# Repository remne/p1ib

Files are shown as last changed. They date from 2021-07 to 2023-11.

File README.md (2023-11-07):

- [P1IB - P1 Interface Bridge](#p1ib---p1-interface-bridge)
  - [Features](#features)
  - [Hardware](#hardware)
  - [Supported smart power meters](#supported-smart-power-meters)
- [Powermeter prerequisite](#powermeter-prerequisite)
- [First time usage](#first-time-usage)
- [Menues](#menues)
  - [Dashboard](#dashboard)
  - [Settings](#settings)
  - [Advanced Settings](#advanced-settings)
  - [Reduced Data Mode](#reduced-data-mode)
- [Firmware update](#firmware-update)
- [Home Assistant](#home-assistant)
  - [Configure MQTT in P1IB](#configure-mqtt-in-p1ib)
  - [Setup the Energy board with p1ib sensors](#setup-the-energy-board-with-p1ib-sensors)
  - [Examples of cards in Home Assistant](#examples-of-cards-in-home-assistant)
    - [Apex charts with energy consumption and electricity spot price from nordpool](#apex-charts-with-energy-consumption-and-electricity-spot-price-from-nordpool)
    - [Example: Current gauges](#example-current-gauges)
  - [Examples of automations in Home Assistant](#examples-of-automations-in-home-assistant)
    - [Example: Disable power switch when fuse amperage is above a given threshold](#example-disable-power-switch-when-fuse-amperage-is-above-a-given-threshold)
- [Homey App](#homey-app)
- [FAQ / Trouble shooting](#faq--trouble-shooting)

# P1IB - P1 Interface Bridge
P1IB (pronounced p-l-i-b) is a software (and hardware) designed to read and parse advanced power meter (AMS) telegrams from the P1
interface port (RJ12) and to send the result to a consumer service, for instance Home Assistant.

Visit [https://remne.tech](https://remne.tech) for more information.

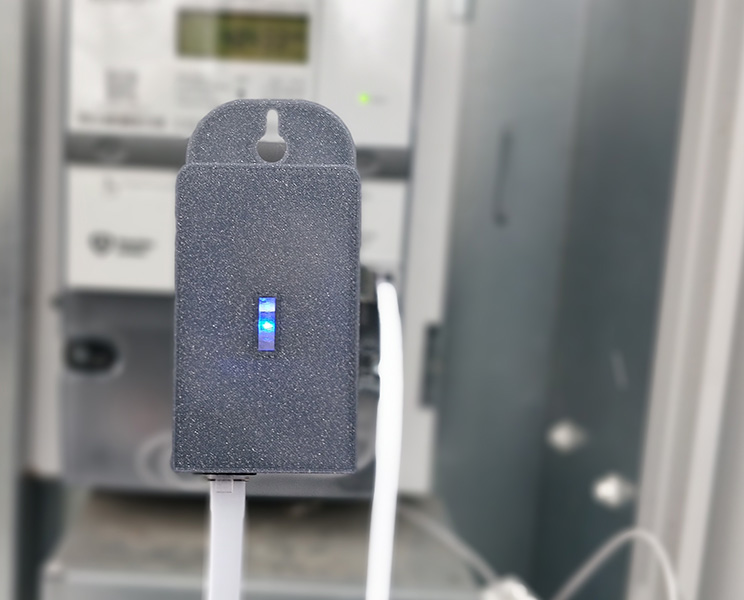
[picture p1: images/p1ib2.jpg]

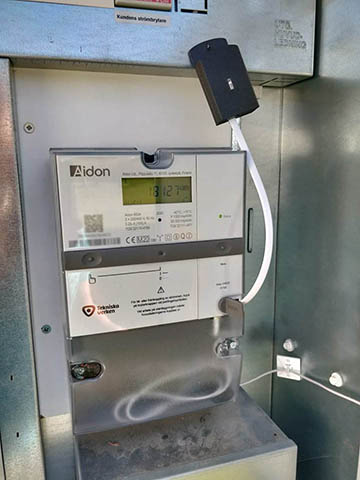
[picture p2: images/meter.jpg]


## Features
- Fully configurable via web UI.
  - WiFi access point
  - DHCP/static ip
  - MQTT settings
  - And lots more...
- Dashboard in web UI with realtime updated graphs for the majority of measurement points from the power meter.
- Supports both protocols that the Swedish meters use at this moment:
  - DLMS/COSEM AXDR/HDLC Mode E (Aidon).
  - DLMS/COSEM ASCII Mode D (The other ones).
- MQTT support.
- Automatic sensor registration for Home Assistant (MQTT Auto Discovery).
- Supports OTA firmware update via web ui (official builds fetched from this github repo).
- Webservice with JSON response of meter data.
- Reduced data mode
- Logging/debug through UDP to a remote computer and/or USB serial.
- P1IB does not require any internet connection (with the exception for over-the-air firmware updates).

## Hardware
The p1ib hardware comes with an RJ12 connector for connecting to the P1 HAN port of the power meter. It also includes an USB port.
The USB port does not need to be connected when plugged in with the RJ12 P1 connection of the power meter. The USB port is only for debugging (and possible changing firmware) purposes.
P1IB is normally powered by the P1 port.

Communication with the p1ib are done through Wi-Fi.

The hardware can normally be bought at [https://remne.tech](https://remne.tech)

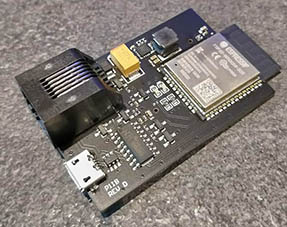
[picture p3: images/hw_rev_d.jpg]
Hardware

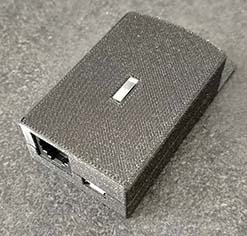
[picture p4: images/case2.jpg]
Case


## Supported smart power meters
Verified to work on the following meters:
- Aidon 6000 & 7000 series (6534 is the most common one, both old and upgraded versions)
- Landis-Gyr E360
- Sagemcom T211/S211
- Sanxing S34U18
- Star STZ351
- Kamstrup OMNIA
- Itron A100/A300
- Kaifa MA304

Will probably work on all Mode D based AMS.

Does not work on:
- ISKRA AM550 (E.on) - E.on cannot activate the P1 port on this meter.
- Kamstrup OMNIPOWER - p1ib can be modified to work with this meter, however, not recommended. OMNIPOWERs P1 port is not compliant with the P1-standard.

# Powermeter prerequisite

To be able to get any information out from the P1 HAN interface on your powermeter, the P1 port needs to be activated.

Visit your electricity grid owners homepage for information on how to activate the P1-port on your powermeter.

# First time usage

1. Connect your p1ib with the RJ12 cable into the P1 port of your AMS. A blue LED light will pulse a couple of times to indicate that it is booting. If no blue LED is blinking, then your HAN/P1 port is not activated. See "Powermeter prerequisite" for instructions.
There is no need to connect a USB cable to the p1ib. It is powered via the P1/HAN interface.

2. P1ib enters AP mode (named "p1ib") when no SSID is configured, or connection cannot be established to the configured SSID.

Connect to Wi-Fi access point named "p1ib" without a password with your preferred device (phone or laptop for instance). You might need to disable "Mobile data" on your phone, otherwise it will try to connect via your cellular network provider.

3. When in AP-mode, IP 192.168.1.1 is set on the p1ib. Go to http://192.168.1.1/ or http://p1ib.local/ with the webbrowser to enter the configuration user interface.

4. Press the menu icon in top left corner, and enter the 'Settings' menu. Here it is possible to scan for your home Wi-Fi accesspoint (SSID), set an SSID password and enable other features.

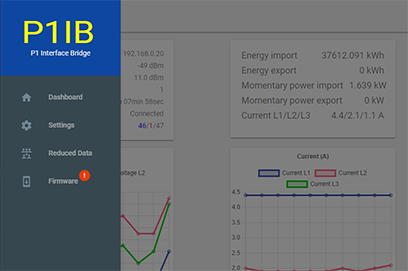
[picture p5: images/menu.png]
Menu


5. Once you have entered your preferred settings, press the "Save & Restart"-button.

6. Now you need to change back to your home Wi-Fi on your mobile phone/laptop. If you are using a device capable of mDNS (all computers more or less, probably not mobile devices) go to url http://p1ib.local/. If you are using a mobile device, you probably need to check in your home router for the IP the p1ib was assigned by your dhcp server, ie go to http://some-ip-number/

7. When entering http://p1ib.local/ (or the IP number) in the webbrowser url you will once again see the dashboard. If you selected correct power meter option in the settings page you will see the graphs beeing updated with your current power consumption.

8. At this point it is recommended press the menu icon once again. If the "firmware" menu option have an *red badge* with an '!' on it, it means that there is a new firmware available. It is recommended to always update to the latest recommended firmware in the firmware-page.

# Menues

## Dashboard
The dashboard provides an overview of the current state of the p1ib, and also graphs for some of the measurement points available.

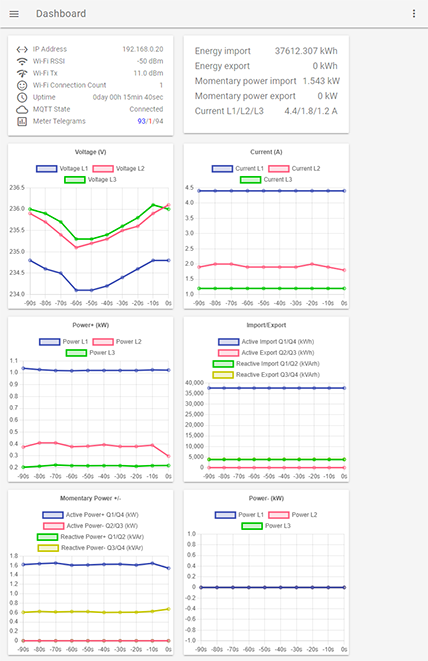
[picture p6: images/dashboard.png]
Dashboard

## Settings

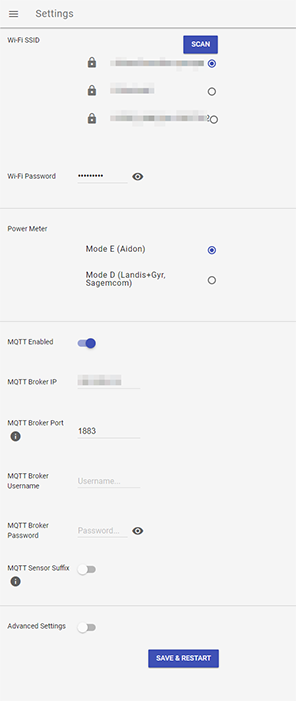
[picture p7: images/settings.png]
Settings

## Advanced Settings

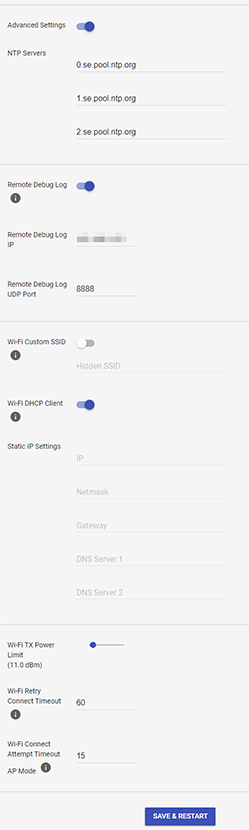
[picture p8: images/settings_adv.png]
Advanced Settings


## Reduced Data Mode

The reduced data mode can be activated if you want to save bandwidth. This is useful for example for remote power monitoring in your summer house or similar where there might be a bandwidth cost from your internet service provider.

Each measurement point can be enabled or disabled, and there is also a hysteresis on each obis code to further limit data bandwidth.

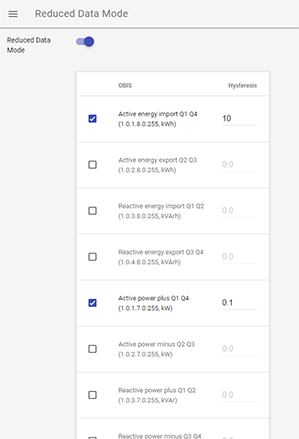
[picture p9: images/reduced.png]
Reduced Data Mode


# Firmware update

When a new firmware is available, a red badge will be visible in the Firmware menu.
The latest stable firmware is marked with the "recommended" text.
To update the firmware, click on the firmware-download icon for the firmware that you want to update to.

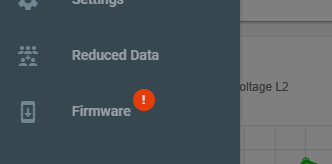
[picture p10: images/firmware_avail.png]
Firmware badge


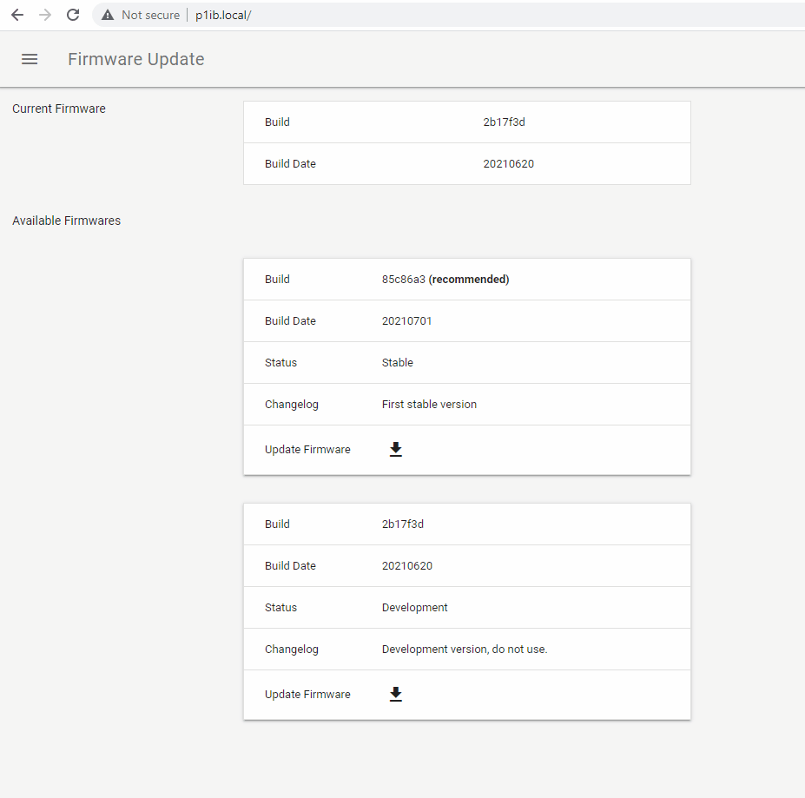
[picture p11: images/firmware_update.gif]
Firmware update


# Home Assistant
An MQTT broker is needed to communicate with Home Assistant. The MQTT broker must be installed separately, and is normally not provided by default in an Home Assistant installation.

Please read the Home Assistant MQTT documentation at https://www.home-assistant.io/integrations/mqtt/ if you dont have an MQTT broker installed.

## Configure MQTT in P1IB
Enable the MQTT client in the *settings* menu. Enter your IP/hostname and port number for your mqtt broker. If authentication is used, username and password must be provided. Once activated and connected, the plib will register a sensor in HA for each measurement point.

Make sure that the *MQTT State* shows **connected** in the dashboard.

MQTT state

<br>
The p1ib registers the sensors in Home Assistant at each startup of the p1ib.

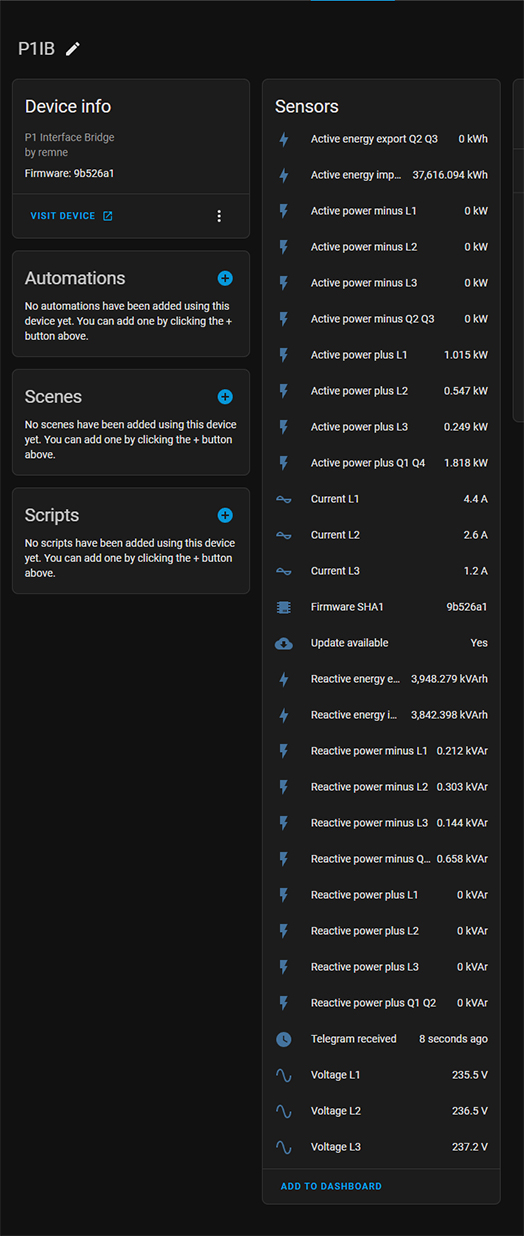
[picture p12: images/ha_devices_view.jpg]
HA Device view

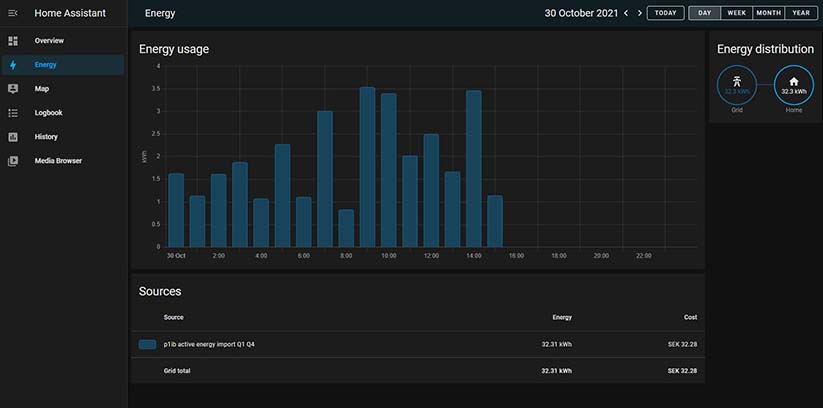
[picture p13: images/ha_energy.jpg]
HA Energy Dashboard


## Setup the Energy board with p1ib sensors

Home Assistant needs som manual configuration to enable it to collect energy statistics over time, and to make the "energy"-dashboard show any p1ib based information.

1. In Home Assistant press "Settings -> Dashboards -> Energy"
2. Add sensors for consumption and return to grid:

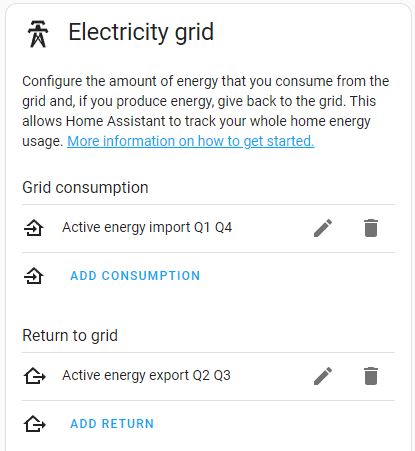
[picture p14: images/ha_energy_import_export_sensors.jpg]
Energy import export
  

1. It will take a couple of hours for Home Assistant to collect data. If it is working as expected, your should finally, after some time, have an dashboard with some nice looking graphs:

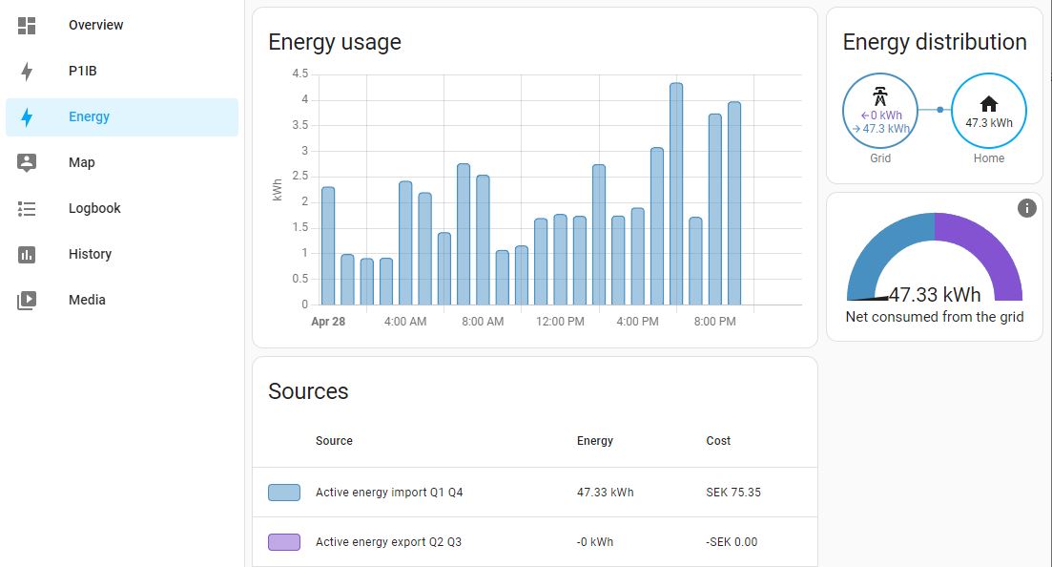
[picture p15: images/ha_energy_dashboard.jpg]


## Examples of cards in Home Assistant

### Apex charts with energy consumption and electricity spot price from nordpool
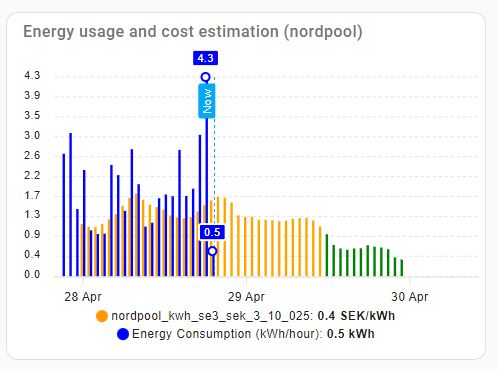
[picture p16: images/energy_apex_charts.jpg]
Energy graph


1. Install apex charts card [https://github.com/RomRider/apexcharts-card](https://github.com/RomRider/apexcharts-card) and nordpool integration [https://github.com/custom-components/nordpool](https://github.com/custom-components/nordpool)

2. Create a per hour energy (kWh) sensor based on the p1ib energy import sensor.
    - Go to home assistant
    - Click Settings -> Devices & Services -> Helpers
    - Click "+ CREATE HELPER"-button
    - Press "Utility Meter"
    - Name the sensor "energy_consumption_kwh_hour"
    - Select sensor "sensor.p1ib_active_energy_import_q1_q4
    - Meter reset cycle: hourly
    - Press "Submit"

3. Go to your dashboard of choice in home assistant, press the "..." icon and "Edit dashboard".

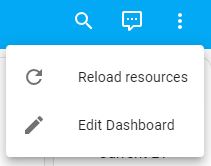
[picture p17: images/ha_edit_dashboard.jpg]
Edit dashboard
   

4. Press the button "+ ADD CARD". Scroll to the bottom and select under Manual, "Need to add a custom card or just want to manually write the YAML?"

Paste the following code into the editor window:
```
type: custom:apexcharts-card
graph_span: 60h
experimental:
  color_threshold: true
header:
  title: Energy usage and cost estimation (nordpool)
  show: true
apex_config:
  yaxis:
    min: 0
hours_12: false
span:
  start: hour
  offset: '-22h'
now:
  show: true
  label: Now
series:
  - entity: sensor.nordpool_kwh_se3_sek_3_10_025
    type: column
    data_generator: |
      return (entity.attributes.raw_today.map((start, index) => {
        return [new Date(start["start"]).getTime(), entity.attributes.raw_today[index]["value"]];
      })).concat(entity.attributes.raw_tomorrow.map((start, index) => {
        return [new Date(start["start"]).getTime(), entity.attributes.raw_tomorrow[index]["value"]];
      }));
    color_threshold:
      - value: 0
        color: green
      - value: 1
        color: orange
      - value: 2
        color: red
      - value: 3
        color: darkred
      - value: 4
        color: black
  - entity: sensor.energy_consumption_kwh_hour
    type: column
    group_by:
      func: max
      duration: 1h
    color: blue
    show:
      header_color_threshold: true
      extremas: true

```

Change the "sensor.nordpool_kwh_se3_sek_3_10_025" to your nordpool sensor of choice in the code above. The sensor is named based on your geographical location.

5. Press "Save". Your done!

### Example: Current gauges

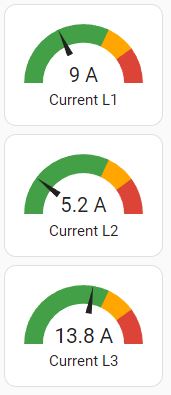
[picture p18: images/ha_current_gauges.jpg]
Current meters


1. Go to your dashboard of choice in home assistant, press the "..." icon and "Edit dashboard".

2. Press the button "+ ADD CARD". Scroll to the bottom and select under Manual, "Need to add a custom card or just want to manually write the YAML?"

3. Paste the following code into the text editor:

```
type: vertical-stack
cards:
  - type: gauge
    entity: sensor.p1ib_current_l1
    max: 25
    unit: A
    needle: true
    severity:
      green: 0
      yellow: 16
      red: 20
  - type: gauge
    entity: sensor.p1ib_current_l2
    max: 25
    unit: A
    severity:
      green: 0
      yellow: 16
      red: 20
    needle: true
  - type: gauge
    entity: sensor.p1ib_current_l3
    max: 25
    unit: A
    needle: true
    severity:
      green: 0
      yellow: 16
      red: 20
view_layout:
  position: sidebar
```

4. Adjust the "green:", "yellow:" and "red:" values based on your main fuse amperage and limits you want to have in the gauges.

5. Press "Save". Your done!

## Examples of automations in Home Assistant

The examples requires some knowledge about the automation system in Home Assistant.
[https://www.home-assistant.io/docs/automation](https://www.home-assistant.io/docs/automation)

### Example: Disable power switch when fuse amperage is above a given threshold

todo: add example

# Homey App

P1IB supports homey! A homey app is available at [https://homey.app/sv-se/app/nu.ahlner.p1ib/p1ib](https://homey.app/sv-se/app/nu.ahlner.p1ib/p1ib)

The app is developed by Erik Ahlner (whyz). Source code available at https://github.com/whyz/homey-p1ib.

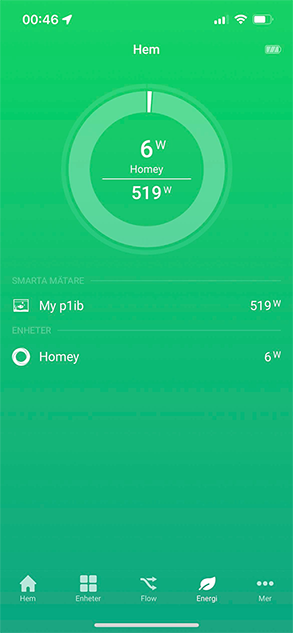
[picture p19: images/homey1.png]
Homey1

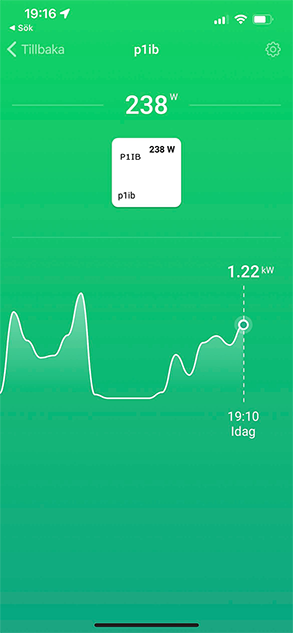
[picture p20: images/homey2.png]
Homey2


# FAQ / Trouble shooting
Q: I have changed WiFi settings and set the p1ib to connect to my home WiFi accesspoint - but I cannot find p1ib on my local network.

A: There are several reasons and solutions:
1. You entered incorrect password for your accesspoint - in this case p1ib will return to AP-mode in a couple of seconds. Wait and watch out for the p1ib-ssid in your wifi scanning.
2. Your device does not support mDNS (http://p1ib.local). You need to figure out what IP-address the p1ib have been assigned to. Go to your router/DHCP-servers client list to find out the IP.
3. Get help in the community facebook group named "P1IB / P1 Interface Bridge - support" (https://www.facebook.com/groups/385403882937131).
4. If 1 och 2 does not solve the problem, then the best way to understand the problem is to connect the p1ib to your PC via USB. Install the CH340 drivers if needed (http://www.wch-ic.com/downloads/CH341SER_EXE.html), linux users doesn't need any drivers). Connect to the usb-serial port with your favorite terminal program (putty for instance), baud rate 2000000. The P1IB will log current state to the usb connection.
5. Flash new firmware onto the device via USB, which will reset all settings and force p1ib to AP-mode. https://remne.github.io/p1ib/webflash/
5. Send email to m.nu (info@m.nu) if you have bought your device from m.nu.
6. Send email to hello@remne.tech.

Q: The LED light pulses with red color, what does it mean?

A: It means p1ib is in AP mode, and needs to be configured. Connect to the Wi-Fi access point named "p1ib" and browse to http://192.168.1.1. You might need to disable "Mobile data" on your phone to be able to access it.

Q: What does the intermitten blue pulse LED light mean?

A: That a power meter messages was correctly parsed and verified (crc check was ok).

Q: What does intermitten red pulses mean?

A: That p1ib received an incomplete message from your powermeter and/or crc check did not pass.

Q: I cannot access p1ib by http://p1ib.local/ after I have selected an access point in the settings menu and entered a password

A1: If p1ib is still available in the devices list of access points, then p1ib could not connect to your AP SSID. Connect to it and double check that you entered the correct password. You can press the 'eye' icon to make the password visible in clear text.

A2: Your client might not support mDNS protocol, which must be activated to be able to resolve p1ib.local to an IP address. If this is the case, use the IP address given by your router instead.

Q: I have Home Assistant and I want all data as sensors.

A: Its easy! Just enable "MQTT" option, enter IP and port and possible username / password to your mqtt broker.
   P1ib automatically register a sensor for each measurement point from your AMS into HA.

Q: I have a different home automation system than HA or Homey I want to use together with my p1ib.

A: MQTT is the prefered protocol in p1ib. Messages will be sent out periodically if connected to an power meter. Easiest way is to
   "sniff" the messages with an local mqtt client (for example mosquitto_sub) to find out all topics available. Subscribe the topic '#' with mosquitto_sub to see all messages and topics.
   There is also a webservice providing the meter data. It can be found att http://p1ib.local/meterData

Q: I cannot see any graphs in the dashboard while in AP mode.

A: The graphs rely on the 'chartjs' library, which is not included in the firmware (due to the library size). Once connected to your Wi-Fi access point (and the internet), the library will be downloaded by your webbrowser and the graphs will work.

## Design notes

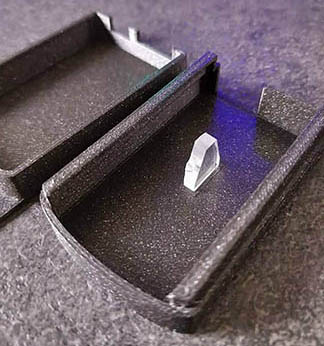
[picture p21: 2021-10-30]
images/case_plexi.jpg

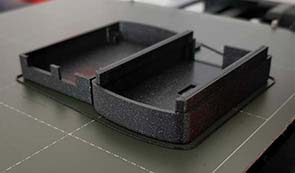
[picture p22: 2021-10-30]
images/case_3dprinting.jpg

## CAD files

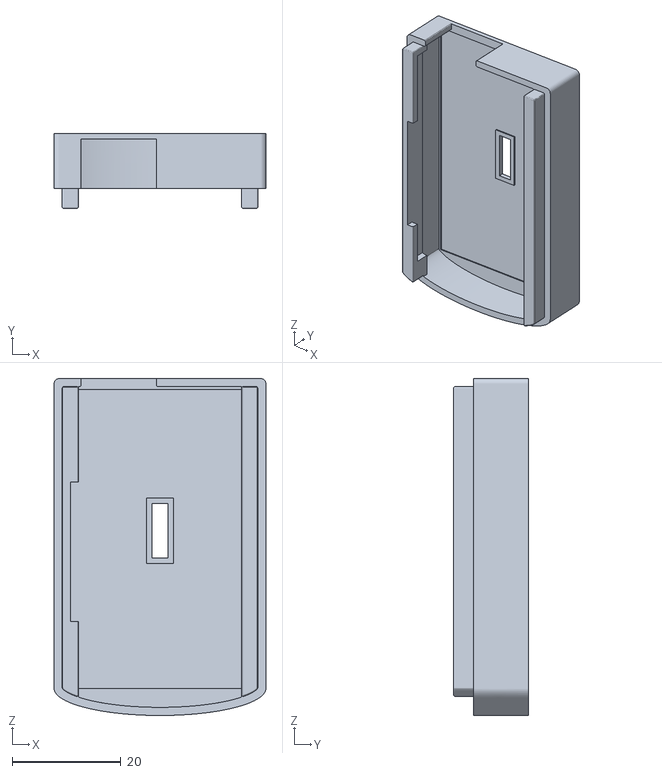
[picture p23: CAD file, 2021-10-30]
case-model/p1ib_top.stl
39.0 x 13.8 x 62.0

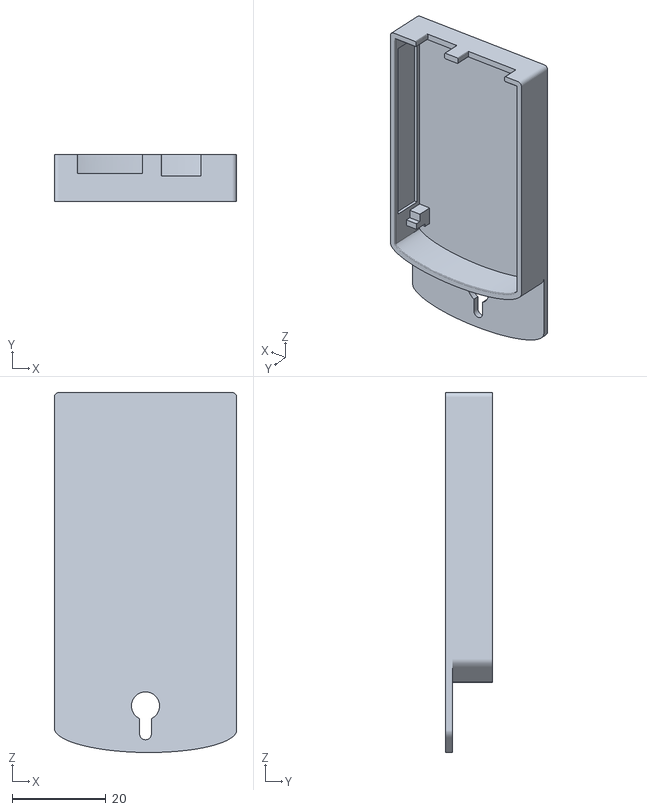
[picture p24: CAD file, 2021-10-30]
case-model/p1ib_bottom.stl
39.0 x 10.0 x 77.0

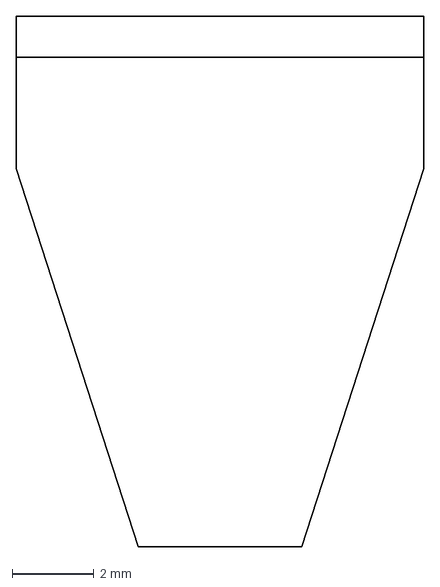
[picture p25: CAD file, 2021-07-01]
case-model/ledthingy.dxf
10.0 x 13.0 mm

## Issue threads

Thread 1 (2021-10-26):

Feature request: Additions to Home assistant auto discovery

egeback, 2021-10-26:
Hi

The home assistant MQTT auto discovery has the possibility to group multiple entries into devices for better mapping. Looking at the current implementation in p1ib it does not to expose this. The optional field is described here:
https://www.home-assistant.io/integrations/sensor.mqtt/#device.

Also the availability tag could be good if data varies or the unit is closed down. Described here https://www.home-assistant.io/integrations/sensor.mqtt/#availability. (This probably needs that p1ib also needs a birth and will message to be added)

**Current exposed json:**
```
{
  "name": "p1ib_active_power_minus_l1",
  "stat_t": "homeassistant/sensor/p1ib/p1ib_active_power_m_l1/state",
  "device_class": "energy",
  "unit_of_measurement": "kW",
  "state_class": "measurement"
}

```
**example from zigbee2mqtt:**
```
{
  "availability": [
    {
      "topic": "zigbee2mqtt/bridge/state"
    }
  ],
 "device": {
    "identifiers": [
      "zigbee2mqtt_0x84fd27fffe6e1d13"
    ],
    "manufacturer": "IKEA",
    "model": "TRADFRI ON/OFF switch (E1743)",
    "name": "....",
    "sw_version": "Zigbee2MQTT 1.21.2"
  },
...
}
zigbee2mqtt/bridge/state: online or offline
```

Regards, Marky

remne, 2021-10-29:
Hi,
Yes, that is true I suppose. I'll look into it!
In the meantime there is a development firmware build you can try out (build b0524da in the p1ib firmware meny), if you want, which adds the device attribute.

Regards,
Andreas

egeback, 2021-10-31:
Hi

Tested the development build and it looks like the device auto discover addition works as expected.. Thanks.

Regards, Marky

remne, 2022-02-05:
Hi Marty,
The latest development firmware have the availability option enabled, if you wanna try it out!

Cheers,
Andreas

egeback, 2022-02-13:
Hi Andreas,

I have tested the build and it works as expected. Tested a reboot and the state was changed.

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

So from my perspective the request is fulfilled, but I guess you want to make a stable release to close the issue.

Best Regards, Marky

remne, 2022-04-30:
Feature in release 97b55c9.

Closed 2022-04-30.

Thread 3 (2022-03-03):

Energy usage differ

dustrat, 2022-03-03:
Hi!

Energy usage in HA versus Tibber differ about 5 kWh/day, Tibber shows the higher value. Any Idea what can cause that? I'm using the sensor sensor.p1ib_active_energy_import_q1_q4 in the Energy Dashboard.

remne, 2022-03-03:
Hi,
I dont know how tibber calculates the energy usage, but the values from the p1ib sensors is the ones your power meter sends out. P1ib does not do any own calculations.

BR,
Andreas

dustrat, 2022-03-03:
Alright, I'll do some digging.

/Patrik

Closed 2022-03-03.

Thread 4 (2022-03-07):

MQTT reconnection behavior

NateRobinsonS, 2022-03-07:
Installation and setup worked as expected.  However, I've noticed that restarting the MQTT broker (Eclipse Mosquitto) causes the connection with the P1ib to break.  It appears that the P1ib doesn't reconnect to the broker automatically, but needs to be restarted via its web interface.  Upon restarting, the P1ib resumes publishing notices to the broker as expected.  More precisely, Home Assistant doesn't find new data from the P1ib.  (I haven't used another method to monitor the MQTT broker directly.)

Currently running the development firmware (f7b009f) on the P1ib.

remne, 2022-03-07:
Hi!
I did a test from my side, and it works as expected with reconnection to the MQTT  broker.

Output from usb/serial port, "<---- <test>" are my added comments:

uptime:406716 ms         IP 192.168.0.217        WiFi TX: 72/78
uptime:411717 ms         IP 192.168.0.217        WiFi TX: 72/78
uptime:416718 ms         IP 192.168.0.217        WiFi TX: 72/78
uptime:421719 ms         IP 192.168.0.217        WiFi TX: 72/78
MQTT: Attempting connection without user/pass...                       <--- MQTT broker shut down by me
[E][WiFiClient.cpp:258] connect(): socket error on fd 59, errno: 104, "Connection reset by peer"
MQTT: failed, Connection Failed
uptime:426720 ms         IP 192.168.0.217        WiFi TX: 72/78
uptime:431721 ms         IP 192.168.0.217        WiFi TX: 72/78
uptime:436722 ms         IP 192.168.0.217        WiFi TX: 72/78
uptime:441723 ms         IP 192.168.0.217        WiFi TX: 72/78
uptime:446724 ms         IP 192.168.0.217        WiFi TX: 72/78
uptime:451725 ms         IP 192.168.0.217        WiFi TX: 72/78
uptime:456726 ms         IP 192.168.0.217        WiFi TX: 72/78
uptime:461727 ms         IP 192.168.0.217        WiFi TX: 72/78
uptime:466728 ms         IP 192.168.0.217        WiFi TX: 72/78
uptime:471729 ms         IP 192.168.0.217        WiFi TX: 72/78
uptime:476730 ms         IP 192.168.0.217        WiFi TX: 72/78
uptime:481731 ms         IP 192.168.0.217        WiFi TX: 72/78
MQTT: Attempting connection without user/pass...                      <-- MQTT reconnect attempt after 1 minute, broker still shut
                                                                                                           down by me.
[E][WiFiClient.cpp:258] connect(): socket error on fd 60, errno: 104, "Connection reset by peer"
MQTT: failed, Connection Failed
uptime:486732 ms         IP 192.168.0.217        WiFi TX: 72/78
uptime:491733 ms         IP 192.168.0.217        WiFi TX: 72/78
uptime:496734 ms         IP 192.168.0.217        WiFi TX: 72/78
uptime:501735 ms         IP 192.168.0.217        WiFi TX: 72/78
uptime:506736 ms         IP 192.168.0.217        WiFi TX: 72/78
uptime:511737 ms         IP 192.168.0.217        WiFi TX: 72/78
uptime:516738 ms         IP 192.168.0.217        WiFi TX: 72/78
uptime:521739 ms         IP 192.168.0.217        WiFi TX: 72/78
uptime:526740 ms         IP 192.168.0.217        WiFi TX: 72/78
uptime:531741 ms         IP 192.168.0.217        WiFi TX: 72/78
uptime:536742 ms         IP 192.168.0.217        WiFi TX: 72/78
uptime:541743 ms         IP 192.168.0.217        WiFi TX: 72/78
MQTT: Attempting connection without user/pass...                 <-- MQTT broker started, and connection was successful during
                                                                                                      next connection attempt.
MQTT: connected!
uptime:546744 ms         IP 192.168.0.217        WiFi TX: 72/78
uptime:551745 ms         IP 192.168.0.217        WiFi TX: 72/78
uptime:556746 ms         IP 192.168.0.217        WiFi TX: 72/78
Resetting buffer                                                                           <-- P1 telegram received
Start found!
Stop found!
Received bytes: 581
Complete packet received!
{
  "0.0.1.0.0.255": "2022-03-07T21:35:50+0100",
  "1.0.1.7.0.255": 3.891,
  "1.0.2.7.0.255": 0,
  "1.0.3.7.0.255": 1.283,
  "1.0.4.7.0.255": 0,
  "1.0.31.7.0.255": 7.5,
  "1.0.51.7.0.255": 5.3,
  "1.0.71.7.0.255": 4.6,
  "1.0.32.7.0.255": 233,
  "1.0.52.7.0.255": 234.3,
...

I also verified from the MQTT broker and in Home Assistant that new data is received.

The behaviour is as expected / as it should be from what I can tell.
Note that the reconnection-timeout is 1 minute between attempts.

Please try again, and let me know if it still doesnt reconnect to the mqtt broker.

Tip: Activate the UDP logging function in the settings menu, then you will receive same debug printouts as the log above to a specified IP/UDP-port. You will need netcat or some other tool. I also have prepared https://github.com/remne/p1ib/tree/master/tools/p1ib_debug.zip which contains an win32 executable that runs a pythonscript that opens a udp port on your computer if you dont have access to some other tool.

BR,
Andreas

NateRobinsonS, 2022-03-08:
According to the log stream from P1ib, it is able to reconnect to the MQTT broker after it starts up again, as expected.  However, HASS doesn't find any information from the P1ib on the MQTT broker until after a restart of the P1ib.  Does it have something to do with autodiscovery?  Is there something that the P1ib publishes when it first connects that it doesn't republish after it loses the MQTT connection?

It's entirely possible that the problem is with HASS and not P1ib.  However, I don't have any problem with the Z-wave JS integration that runs through the same MQTT server.  It reconnects after the MQTT server restarts, exactly as it should.

Can you reproduce the connection problem in HASS?  I'm running 2022.3.1 with the MQTT integration configured via the front end (not via YAML).  I don't find any errors in HASS' logfile, but I only have Warnings and above activated at the moment.

-Nate

remne, 2022-03-08:
You are correct, the p1ib only registeres sensors once during startup. I thought that was good enough, but I can change that behavior of course.

The reasoning for this behavior was that I suppose that normally one doesnt reset all HA configuration that often (or never? I haven't done it for the last 4 years), and that it was good enough to register sensors once at restart of the p1ib.

BR,
Andreas

NateRobinsonS, 2022-03-08:
This one (also) appears to be on my side.  I found a typo in the config file for the MQTT broker.  The persistent data wasn't being saved at shutdown.  After resolving the issue, I can confirm that HA starts importing p1ib data via the broker as soon as the broker is available again (without restarting the p1ib).

radhus, 2023-03-14:
Hi @remne ,

> You are correct, the p1ib only registeres sensors once during startup. I thought that was good enough, but I can change that behavior of course.

I think this would be nice, as otherwise we'll have to have persistence on the MQTT server and/or make sure to restart p1ib in case you would reinstall the MQTT server. Maybe not the big of an hassle, but perhaps it could be changed to publish every time you have (re)connected to the MQTT server?

I haven't looked at the code base yet, so not sure how hard it would be. Perhaps I can try to take a look later. Let me know if I should open a new issue instead.

Thanks for this software and hardware, works great!

Closed 2022-03-08.

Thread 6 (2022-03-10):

Wi-fi reconnection

NateRobinsonS, 2022-03-10:
Hej,

What does the p1ib do if the wi-fi connection is interrupted?  From what I can tell, it goes into AP mode and doesn't try to reconnect to the wi-fi (at least within 10-20 minutes) without a restart.  Is this the intended behavior?

-Nate

remne, 2022-03-10:
Hi,

That is correct, if it looses wifi connection and cannot reconnect immediately it will go into AP-mode, and it will be in AP-mode for at least 15minutes. After 15minutes, it will scan SSID's, and if the configured one is found, a new connection attempt is executed.

The reasoning for the (long) 15minutes interval is that otherwise there will be too small window of opportunity to configure the p1ib settings until you are disconnected from AP-mode. I've experimented with less, and there have been some persons that misstyped their password, and then it got a bit difficult to change it.

I'm planning to make all timeout/interval-settings configurable in the web UI.

BR,
Andreas

NateRobinsonS, 2022-04-04:
I have the p1ib "installed" about 1 meter from our wifi base station and within close range of a second mesh point.  In other words, wifi connectivity shouldn't be a problem.  However, it loses contact at irregular intervals about once a day, sometimes several times a day.  This wouldn't be an issue if it recovered within a minute or so.  However, losing 15 minutes of data every time there's a hiccup means missing the price change of electricity at the end of the hour quite regularly.  In my opinion, the p1ib needs to attempt to reconnect several times before defaulting to AP mode for 15 minutes as it does now..

If the issue is preventing the user from "locking themselves out" of the p1ib because the wifi settings on the device are incorrect, might I suggest one of the following solutions?
- The P1ib tries to reconnect to the programmed wifi every 10 seconds for 15 minutes, at which point it gives up and returns to AP mode for 15 minutes before trying to reconnect again for 15 mintues, etc.
- The P1ib tries to reconnect continuously, but can be reset to "factory defaults" by disconnecting and reconnecting the power 5 times within one minute (since there's no hardware switch to use for a reset).

-Nate

remne, 2022-04-05:
For sure, things can probably be tweaked a bit.
But I rather not have it to try much longer than it is today before entering AP mode. That would be frustrating in the case that you actually need it to enter AP mode.

As it is right now, it will retry 3 times after a disconnect, then wait 5 seconds, and then retries 3 times again after each other. This attempt-cycle is done 5 times before entering AP mode. So a total of 15 times over a period of 15 seconds which should be enough time between an AP restart, which I suppose is the most common reason for a wifi disconnect.

Debug log:
WIFI: No wifi connection, reconnecting...
WIFI: Connecting to AP access_point...
WIFI: Retrying connection (attempt 0, tx=40, wifi status=1)...
WIFI: Retrying connection (attempt 1, tx=40, wifi status=1)...
WIFI: Retrying connection (attempt 2, tx=40, wifi status=1)...
uptime:372s      IP 0.0.0.0      WiFi TX: 34/40
WIFI: No wifi connection, reconnecting...
WIFI: Connecting to AP access_point...
WIFI: Retrying connection (attempt 0, tx=40, wifi status=1)...
WIFI: Retrying connection (attempt 1, tx=40, wifi status=1)...
WIFI: Retrying connection (attempt 2, tx=40, wifi status=1)...
uptime:377s      IP 0.0.0.0      WiFi TX: 34/40
WIFI: No wifi connection, reconnecting...
WIFI: Connecting to AP access_point...
WIFI: Retrying connection (attempt 0, tx=40, wifi status=1)...
WIFI: Retrying connection (attempt 1, tx=40, wifi status=1)...
WIFI: Retrying connection (attempt 2, tx=40, wifi status=1)...
uptime:382s      IP 0.0.0.0      WiFi TX: 34/40
WIFI: No wifi connection, reconnecting...
WIFI: Connecting to AP access_point...
WIFI: Retrying connection (attempt 0, tx=40, wifi status=1)...
WIFI: Retrying connection (attempt 1, tx=40, wifi status=1)...
WIFI: Retrying connection (attempt 2, tx=40, wifi status=1)...
uptime:387s      IP 0.0.0.0      WiFi TX: 34/40
WIFI: No wifi connection, reconnecting...
WIFI: Connecting to AP access_point...
WIFI: Retrying connection (attempt 0, tx=40, wifi status=1)...
WIFI: Retrying connection (attempt 1, tx=40, wifi status=1)...
WIFI: Retrying connection (attempt 2, tx=40, wifi status=1)...
WIFI: Retry count exceeded.
WIFI: Switching to AP mode...
WIFI: Now in AP mode. Connect your station to SSID 'p1ib'.
WIFI: P1IB have IP: 192.168.1.1

But as I wrote earlier, I will make these parameters configurable in the web ui, so it can be tweaked for custom needs.

However from what you are writing, the root problem seems to be that it actually disconnects at all. This should of course not happen. For example my own doesnt disconnect at all, last time I checked before restarting it had 47 days uptime without any reconnections to wifi.

I dont know if it depends on ESP32's wifi in combination with your AP (or the mesh) is the problem or something else. I would say it have nothing to do with the p1ib software, as it uses the espIDF framework for wifi connectivity.
I do though now that there have been reports with connection issues with certain AP's with the ESP series of wifi mcu's from reading forum posts and suchs.

Might I ask if you have some old AP laying around that you can try with temporary, to rule out your AP's in combination with the ESP32?
Or disable your AP mesh for a day or two and see it that does the trick?
If that doesnt help, it might be a problem with your p1ib hardware. Bad/glitchy pcb-antenna maybe? I always test all devices before I send them out (wifi connectivitivy, P1 port and cable), but I don't, for obvious reasons, test each device over longer periods of time.

/Andreas

NateRobinsonS, 2022-04-07:
I'm definitely not trying to pin the source of the disconnection problem on
the p1ib (hardware or software).  I'm running Asus' "Zen wifi" XT8 and it
seems to have a few bugs, particularly with "IOT devices".  I suspect that
there is radio interference here with the 2.4 GHz band (some devices
have trouble with Bluetooth connectivity in the house as well).

Instead, I'd like to set the device up to recover quickly.  As you suggest,
a setting to adjust the "timeout" before switching over to AP mode and/or
how frequently it leaves AP mode (presuming that there is nothing connected
via HTTP) to look for the previous wifi would solve this.

Do your APs restart in 15 seconds?  If I restart the Asus mesh, it takes a
few minutes to come back up.

-Nate

On Tue, Apr 5, 2022 at 5:00 PM Andreas Remnehed ***@***.***>
wrote:

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

NateRobinsonS, 2022-04-07:
Thanks. I'll try it out.

-Nate

On Thu, 7 Apr 2022, 11:33 Andreas Remnehed, ***@***.***>
wrote:

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

remne, 2022-04-22:
Hi Nate,
Hows it going with your reconnection issues? Did it help out anything with the possibility to modify the timeout values for reconnection etc?

BR,
Andreas

NateRobinsonS, 2022-04-23:
Absolutely.  I set the Wifi Retry Connect timeout to 120 seconds and the
Wifi Wi-Fi Connect Attempt Timeout In AP Mode to 5 minutes.  The device
hasn't been offline for 15 minutes (when a HA automation would send me a
notice) since the update.

Thanks!

-Nate

On Fri, Apr 22, 2022 at 10:38 PM Andreas Remnehed ***@***.***>
wrote:

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

Closed 2022-03-29.

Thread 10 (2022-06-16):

How to delete orphan entities?

johanschelin, 2022-06-16:
Hi!

I purchased this, but my Meter didn't support opening the P1 port, so I sold it to a friend.
I have all my entites still in Home Assistant, and cannot find a way to delete them? :)

This entity ('sensor.p1ib_active_power_minus_l1') does not have a unique ID, therefore its settings cannot be managed from the UI. See the [documentation](https://www.home-assistant.io/faq/unique_id) for more detail.

johanschelin, 2022-06-16:
I believe that I should send an empty message with the Retain flag, but I am a MQTT beginner, so I'm not sure what topic i should send it to.
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

remne, 2022-06-25:
Hi!
I guess you have one of the earlier firmwares.
For newer ones you just go to "settings -> devices & Services -> Devices" and press "delete device".
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

The other way (before the firmware supported the device-entry in HA) is to send an mqtt message to the Home Assistant "config" topic with an empty payload.
I have a script for this, which deletes all sensors. From this you can find the topics. It have changed a bit during the development of the p1ib firmware, so I'm not sure which one you have. Probably the sensornames are the ones in the bottom of the script without the prefix-part.
Probably "homeassistant/sensor/p1ib/p1ib_h_active_imp_q1_q4/config" for example. Try it out and see if it works!

$ cat unregister_all_sensors.sh
#!/bin/bash

ARG=$1
SUFFIX=""

if [ -z "$ARG" ]
then
    echo "empty suffix"
else
    SUFFIX="${ARG}"
    echo "adding suffix \"${SUFFIX}\" to topics"
fi

set -x

mosquitto_pub -h 192.168.0.5 -p 1883 -t "homeassistant/sensor/p1ib/p1ib_${SUFFIX}h_active_imp_q1_q4/config" -m ''
mosquitto_pub -h 192.168.0.5 -p 1883 -t "homeassistant/sensor/p1ib/p1ib_${SUFFIX}h_active_exp_q2_q3/config" -m ''
mosquitto_pub -h 192.168.0.5 -p 1883 -t "homeassistant/sensor/p1ib/p1ib_${SUFFIX}h_reactive_imp_q1_q2/config" -m ''
mosquitto_pub -h 192.168.0.5 -p 1883 -t "homeassistant/sensor/p1ib/p1ib_${SUFFIX}h_reactive_exp_q3_q4/config" -m ''
mosquitto_pub -h 192.168.0.5 -p 1883 -t "homeassistant/sensor/p1ib/p1ib_${SUFFIX}active_power_p_q1_q4/config" -m ''
mosquitto_pub -h 192.168.0.5 -p 1883 -t "homeassistant/sensor/p1ib/p1ib_${SUFFIX}active_power_m_q2_q3/config" -m ''
mosquitto_pub -h 192.168.0.5 -p 1883 -t "homeassistant/sensor/p1ib/p1ib_${SUFFIX}reactive_power_p_q1_q2/config" -m ''
mosquitto_pub -h 192.168.0.5 -p 1883 -t "homeassistant/sensor/p1ib/p1ib_${SUFFIX}reactive_power_m_q3_q4/config" -m ''
mosquitto_pub -h 192.168.0.5 -p 1883 -t "homeassistant/sensor/p1ib/p1ib_${SUFFIX}active_power_p_l1/config" -m ''
mosquitto_pub -h 192.168.0.5 -p 1883 -t "homeassistant/sensor/p1ib/p1ib_${SUFFIX}active_power_m_l1/config" -m ''
mosquitto_pub -h 192.168.0.5 -p 1883 -t "homeassistant/sensor/p1ib/p1ib_${SUFFIX}active_power_p_l2/config" -m ''
mosquitto_pub -h 192.168.0.5 -p 1883 -t "homeassistant/sensor/p1ib/p1ib_${SUFFIX}active_power_m_l2/config" -m ''
mosquitto_pub -h 192.168.0.5 -p 1883 -t "homeassistant/sensor/p1ib/p1ib_${SUFFIX}active_power_p_l3/config" -m ''
mosquitto_pub -h 192.168.0.5 -p 1883 -t "homeassistant/sensor/p1ib/p1ib_${SUFFIX}active_power_m_l3/config" -m ''
mosquitto_pub -h 192.168.0.5 -p 1883 -t "homeassistant/sensor/p1ib/p1ib_${SUFFIX}reactive_power_p_l1/config" -m ''
mosquitto_pub -h 192.168.0.5 -p 1883 -t "homeassistant/sensor/p1ib/p1ib_${SUFFIX}reactive_power_m_l1/config" -m ''
mosquitto_pub -h 192.168.0.5 -p 1883 -t "homeassistant/sensor/p1ib/p1ib_${SUFFIX}reactive_power_p_l2/config" -m ''
mosquitto_pub -h 192.168.0.5 -p 1883 -t "homeassistant/sensor/p1ib/p1ib_${SUFFIX}reactive_power_m_l2/config" -m ''
mosquitto_pub -h 192.168.0.5 -p 1883 -t "homeassistant/sensor/p1ib/p1ib_${SUFFIX}reactive_power_p_l3/config" -m ''
mosquitto_pub -h 192.168.0.5 -p 1883 -t "homeassistant/sensor/p1ib/p1ib_${SUFFIX}reactive_power_m_l3/config" -m ''
mosquitto_pub -h 192.168.0.5 -p 1883 -t "homeassistant/sensor/p1ib/p1ib_${SUFFIX}voltage_l1/config" -m ''
mosquitto_pub -h 192.168.0.5 -p 1883 -t "homeassistant/sensor/p1ib/p1ib_${SUFFIX}voltage_l2/config" -m ''
mosquitto_pub -h 192.168.0.5 -p 1883 -t "homeassistant/sensor/p1ib/p1ib_${SUFFIX}voltage_l3/config" -m ''
mosquitto_pub -h 192.168.0.5 -p 1883 -t "homeassistant/sensor/p1ib/p1ib_${SUFFIX}current_l1/config" -m ''
mosquitto_pub -h 192.168.0.5 -p 1883 -t "homeassistant/sensor/p1ib/p1ib_${SUFFIX}current_l2/config" -m ''
mosquitto_pub -h 192.168.0.5 -p 1883 -t "homeassistant/sensor/p1ib/p1ib_${SUFFIX}current_l3/config" -m ''

mosquitto_pub -h 192.168.0.5 -p 1883 -t "homeassistant/sensor/p1ib_${SUFFIX}/p1ib_h_active_imp_q1_q4/config" -m ''
mosquitto_pub -h 192.168.0.5 -p 1883 -t "homeassistant/sensor/p1ib_${SUFFIX}/p1ib_h_active_exp_q2_q3/config" -m ''
mosquitto_pub -h 192.168.0.5 -p 1883 -t "homeassistant/sensor/p1ib_${SUFFIX}/p1ib_h_reactive_imp_q1_q2/config" -m ''
mosquitto_pub -h 192.168.0.5 -p 1883 -t "homeassistant/sensor/p1ib_${SUFFIX}/p1ib_h_reactive_exp_q3_q4/config" -m ''
mosquitto_pub -h 192.168.0.5 -p 1883 -t "homeassistant/sensor/p1ib_${SUFFIX}/p1ib_active_power_p_q1_q4/config" -m ''
mosquitto_pub -h 192.168.0.5 -p 1883 -t "homeassistant/sensor/p1ib_${SUFFIX}/p1ib_active_power_m_q2_q3/config" -m ''
mosquitto_pub -h 192.168.0.5 -p 1883 -t "homeassistant/sensor/p1ib_${SUFFIX}/p1ib_reactive_power_p_q1_q2/config" -m ''
mosquitto_pub -h 192.168.0.5 -p 1883 -t "homeassistant/sensor/p1ib_${SUFFIX}/p1ib_reactive_power_m_q3_q4/config" -m ''
mosquitto_pub -h 192.168.0.5 -p 1883 -t "homeassistant/sensor/p1ib_${SUFFIX}/p1ib_active_power_p_l1/config" -m ''
mosquitto_pub -h 192.168.0.5 -p 1883 -t "homeassistant/sensor/p1ib_${SUFFIX}/p1ib_active_power_m_l1/config" -m ''
mosquitto_pub -h 192.168.0.5 -p 1883 -t "homeassistant/sensor/p1ib_${SUFFIX}/p1ib_active_power_p_l2/config" -m ''
mosquitto_pub -h 192.168.0.5 -p 1883 -t "homeassistant/sensor/p1ib_${SUFFIX}/p1ib_active_power_m_l2/config" -m ''
mosquitto_pub -h 192.168.0.5 -p 1883 -t "homeassistant/sensor/p1ib_${SUFFIX}/p1ib_active_power_p_l3/config" -m ''
mosquitto_pub -h 192.168.0.5 -p 1883 -t "homeassistant/sensor/p1ib_${SUFFIX}/p1ib_active_power_m_l3/config" -m ''
mosquitto_pub -h 192.168.0.5 -p 1883 -t "homeassistant/sensor/p1ib_${SUFFIX}/p1ib_reactive_power_p_l1/config" -m ''
mosquitto_pub -h 192.168.0.5 -p 1883 -t "homeassistant/sensor/p1ib_${SUFFIX}/p1ib_reactive_power_m_l1/config" -m ''
mosquitto_pub -h 192.168.0.5 -p 1883 -t "homeassistant/sensor/p1ib_${SUFFIX}/p1ib_reactive_power_p_l2/config" -m ''
mosquitto_pub -h 192.168.0.5 -p 1883 -t "homeassistant/sensor/p1ib_${SUFFIX}/p1ib_reactive_power_m_l2/config" -m ''
mosquitto_pub -h 192.168.0.5 -p 1883 -t "homeassistant/sensor/p1ib_${SUFFIX}/p1ib_reactive_power_p_l3/config" -m ''
mosquitto_pub -h 192.168.0.5 -p 1883 -t "homeassistant/sensor/p1ib_${SUFFIX}/p1ib_reactive_power_m_l3/config" -m ''
mosquitto_pub -h 192.168.0.5 -p 1883 -t "homeassistant/sensor/p1ib_${SUFFIX}/p1ib_voltage_l1/config" -m ''
mosquitto_pub -h 192.168.0.5 -p 1883 -t "homeassistant/sensor/p1ib_${SUFFIX}/p1ib_voltage_l2/config" -m ''
mosquitto_pub -h 192.168.0.5 -p 1883 -t "homeassistant/sensor/p1ib_${SUFFIX}/p1ib_voltage_l3/config" -m ''
mosquitto_pub -h 192.168.0.5 -p 1883 -t "homeassistant/sensor/p1ib_${SUFFIX}/p1ib_current_l1/config" -m ''
mosquitto_pub -h 192.168.0.5 -p 1883 -t "homeassistant/sensor/p1ib_${SUFFIX}/p1ib_current_l2/config" -m ''
mosquitto_pub -h 192.168.0.5 -p 1883 -t "homeassistant/sensor/p1ib_${SUFFIX}/p1ib_current_l3/config" -m ''

johanschelin, 2022-07-09:
Sorry for the late reply

Sending empty payloads to the config topic removes the sensor temporarily. But a restart makes it pop back again. Can I do this in another way? I'm sending the messages via the MQTT Integration.

remne, 2022-07-09:
You need to clear the messages in the mqtt broker probably (they might be stored as retained messages)
Read about it here:
https://community.openhab.org/t/clearing-mqtt-retained-messages/58221

johanschelin, 2022-07-09:
Excellent, doing this for every topic deleted them correctly - thanks

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

Closed 2022-07-09.

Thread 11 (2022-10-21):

Problem with saving settings after scaninig Wifi network in build 97b55c9

Pewah, 2022-10-21:
After upgrading to build 97b55c9, all settings disappeared. After clicking the Scan button for Wifi network the "Save Settings" button remained disabled. A workaround was to enter custom SSID and at that time the "Save settings" button was clickable.

egeback, 2023-05-04:
Another workaround is to inspect the webpage in Chrome and remove the disabled ccs tag.

remne, 2023-05-04:
Hi,
Sorry for the issue. Its an bug in the p1ib javascript parts during wifiscan in certain conditions. It will be corrected in a firmware during the weekend.
Thanks for reporting the problem.

remne, 2023-06-12:
Hi,
Fixed in firmware e74c477.

Regards
Andreas

Closed 2023-06-12.

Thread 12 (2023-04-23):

Not able to OTA upgrade to fcd8d4a

bckstrm, 2023-04-23:
I have some problems with p1ib not reconnecting after temporary loosing wifi-connection and i wanted to test the development firmware to see if this has been solved but every time i try to upgrade firmware from 97b55c9 to fcd8d4a it fails with error message "Error in server response!".

remne, 2023-04-24:
Hi,
P1IB normally enters AP-mode for a given time (timers can be modified in the web configuration) when it cannot find the configured SSID while loosing the signal. If your wifi-signal is received very poorly, this can happen. It will stay in AP-mode for default 15 minutes, then scan again and reconnect to your ssid (if found).

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

But from your question in hand, it sounds like that the upgrade gets interrupted due to poor wifi signal.
Would it be possible that you move your p1ib close to the wifi-accesspoint temporary (powering it by USB), and retry?

Regards
Andreas

bckstrm, 2023-05-01:
I'm sorry, problem was at my end (VLAN was blocked from internet). I will try if the retry trigger works better with the latest firmware, thanks!

Closed 2023-05-01.

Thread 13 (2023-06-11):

Feature request: composite MQTT messages

albinsunnanbo, 2023-06-11:
Currently p1ib publishes 1 topic per metric.
It would be nice if there would be an option to get a single topic with a composite JSON document with all metrics instead.
This would simplify some calculations and improve performance for some clients.

remne, 2023-06-12:
Hi,
Thanks for the request.
I will add this feature in next coming development firmware.

Regards,
Andreas

albinsunnanbo, 2023-06-15:
Thanks
It would be nice if you could also trim leading zeroes, like in
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
Some libraries are really strict about number formatting

remne, 2023-09-14:
Json payload for sensors states is nov available in dev firmware (2023-09-14, adcc0f7).

Closed 2023-10-02.

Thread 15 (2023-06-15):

Feature request: AWS IoT hub compatibility

albinsunnanbo, 2023-06-15:
I plan to use AWS IoT for analyzing the smart meter data.
I tried and had to write a wrapper layer, but with a few tweaks it works. It would be nice if the p1ib could support those things out of the box.
* Needs JSON payloads, not plain strings - https://github.com/remne/p1ib/issues/13 would solve that issue
* Can't handle leading zeroes, for example in
  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
  I suppose this will also be fixed in - https://github.com/remne/p1ib/issues/13
* Needs mutual TLC with X.509 client certificates, a way to upload and use a X.509 client certificate and Root CA to be used - https://docs.aws.amazon.com/whitepapers/latest/device-manufacturing-provisioning/resources-on-the-device.html

Azure IoT hub seems to have similar requirements although it seems to require username and can alternatively use an authentication key instead of X.509 certificate
https://learn.microsoft.com/en-us/azure/iot/iot-mqtt-connect-to-iot-hub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

remne, 2023-07-07:
Hi,
TLS support for MQTT is in progress, will be released in a near future.

/Andreas

remne, 2023-08-04:
Hi!
Latest development firmware supports MQTT TLS (AWS IoT Core).

However, I have not finished json payloads yet.
I'm not sure however why you "need" json objects for AWS? Its no problem to run with plain strings to the AWS MQTT broker. But I guess its your specific solution that needs json objects?

BR,
Andreas

LindquistS, 2023-08-23:
The supplier is RemneTech, I am currently looking at their suitability as a supplier.

Closed 2023-09-22.

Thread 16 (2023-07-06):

Looking for technical details regarding Kamstrup OMNIPOWER Three-phase meter DK-8660

christofferholmstedt, 2023-07-06:
I just moved to a newly built house where the electricity company has installed the Kamstrup OMNIPOWER Three-pase meter DK-8660. I see in a lot of web shops for various devices that the OMNIPOWER is not supported, but rarely any details on what exactly is wrong with this specific meter.

I see in the README.md that the P1ib can be modified to support my OMNIPOWER but not recommended. Can anyone here share some more technical details what is actually wrong with the OMNIPOWER and what needs to be modified in the P1ib?

Any help is appreciated before I go down the rabbit hole of trying to figure it out myself.

remne, 2023-07-07:
The omnipower meter dosnt comply to the P1-standard.
- it doenst have any power supply in the hardware interface
- the baudrate can vary (based on grid owner configuration)
- the payload can differ (based on grid owner configuration)
- sometimes its a mess between how the software is configured against the installed interface-module on the meter, even if the module is installed as a P1-module, the grid owners doesnt know themselfs sometimes or how to configure it correctly to get the expected output.

...its all a mess.

I've helped a couple of customers of the p1ib to make it work with the kamstrup omnipower, but it takes often several phone calls to the grid owner, both to get hold of a person that knows anything, and some soldering on the p1ib.

The p1ib itselfs needs to be patched with one cable, to power the p1-interface to be powered by usb instead of via the p1 interface. Its not difficult if you have some earlier experience with soldering. The problematic part is to make the grid owner to realize how to configure their meter.

Regards
Andreas

orfeasKalipolitis, 2024-03-08:
Hello,

Newbiew with the P1IB here, based in Sweden.

I missed the part where OMNIA and OMNIPOWER are different unfortunately before I bought the device. But I really like the idea and the implementation so I would like to stick with it.

Could you perhaps let us know what you told the grid owner so that we can take our chances with them directly? In my case, since it is quite a small outfit, I believe I could more easily talk to someone technical and if I can give them a good enough description, end up with a solution.

Thanks in advance. Amazing project!

remne, 2024-03-08:
Hi,
As it requires so much and time effort (both mine and yours, as it always results in me having to put in hours in support mails etc) I would recommend that you return your device instead.
The devices is also sold as not supporting the OMNIA as you've already mentioned.

Sorry for the inconvience.

Regards,
Andreas

orfeasKalipolitis, 2024-03-08:
Hi,

Would it be possible to just give a written description of the info you've had to give them in the past?

On the README it still states that it could be possible to connect to this meter. While I understand it may be complicated, I would like to give it a try.

I also completely understand that you don't want to put too much effort into it, as you know it is really time intensive and difficult to solve for everyone, hence the suggestion of just providing that information as some text that we can take on our own and try to irk out a solution.

Thanks in advance.

Orfeas

ipkryss, 2024-03-11:
I'm wondering the same thing! Also just bought a house and saw that I have an omnipower meeter and that it's not supported.

I found some other products that does support the omnipower so I wonder how they achieved that considering this one couldn't - I'd much rather support this project compared to the other solutions I've found.

remne, 2024-03-12:
I didnt design the hardware to be non DSMR5/P1 compatible. One can patch the PCB to make it work to power some parts of the hardware to work with the Kamstrup meter. But this is also the reason why I'm hesitant to put out the instructions, because people in general more often than seldom doesnt solder and will in some cases most likely destroy their P1IB.
The other is as mentioned before the problem with grid owners and their limited knowledge of configuring their own meters. I would hope that it has improved since I had to support in this area, since it was some time ago. And most likely people are using their meters more often today with some P1-dongle/device.

But as you both seem very keen on getting this up'n'running, send me an mail at hello@remne.tech, and we can take it from there.

orfeasKalipolitis, 2024-03-13:
Thank you Andreas.
I sent an email :)
P.S. my OmniPower should have the latest firmware installed, I just had the local tech update it.

ipkryss, 2024-03-15:
Thanks for replying Remne, but I will not bother you with this. Seems like too big of a project if soldering is necessary even though I am not afraid of doing some soldering usually.

Is there no chance that it will work out-of-the-box with the latest firmware installed as orfeaskalipolitis mentions?

Closed 2023-07-12.

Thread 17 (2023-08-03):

HA Entities Warning

dustrat, 2023-08-03:
Hello!

I recently saw this warning popup i Home Assistant:
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

Anything I can do in HA to fix this or is a firmware fix required?

/P

remne, 2023-08-04:
Hi!

I have create a development firmware that alignes sensor names to HA's new naming conventions (removed p1ib from the name).
However, its just a warning in HA. It can be ignored if one dont want to run a development (test) firmware until it is set as stable (or bugs identified and fixed).

BR,
Andreas

dustrat, 2023-08-04:
Alright, good to know.

Closed 2024-02-27.

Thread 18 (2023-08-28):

Non decimal in current

JelpirT, 2023-08-28:
I got no decimals in current flow? any ide how to get it?
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

remne, 2023-09-14:
Hi,
What power meter do you have?
I'm not familiar with that model.

To help out to understand why p1ib decodes the information without decimals I need a sample payload. You can get it by activating the remote debug or hooking up the p1ib to usb and connecting to the serial port with a terminal program (2'000'000 baud rate)

Regards,
Andreas

JelpirT, 2023-09-14:
Hej, jag har denna mätare, vet ej vilken ip debug ska aktiveras till?Skickat från min Galaxy
-------- Originalmeddelande --------Från: Andreas Remnehed ***@***.***> Datum: 2023-09-14  22:51  (GMT+01:00) Till: remne/p1ib ***@***.***> Kopia: JelpirT ***@***.***>, Author ***@***.***> Ämne: Re: [remne/p1ib] Non decimal in current (Issue #18)
Hi,
What power meter do you have?
I'm not familiar with that model.
To help out to understand why p1ib decodes the information without decimals I need a sample payload. You can get it by activating the remote debug or hooking up the p1ib to usb and connecting to the serial port with a terminal program (2'000'000 baud rate)
Regards,
Andreas

—Reply to this email directly, view it on GitHub, or unsubscribe.You are receiving this because you authored the thread.Message ID: ***@***.***>

JelpirT, 2023-09-19:
Edit the answer

remne, 2023-10-02:
hi, please contact hello @ remne . tech instead via email!

Closed 2023-10-02.

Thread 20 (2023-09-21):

Entity state class warnings

johanschelin, 2023-09-21:
Logger: homeassistant.components.sensor
Source: components/sensor/__init__.py:500
Integration: Sensor (documentation, issues)
First occurred: 18:57:56 (3 occurrences)
Last logged: 19:12:03

Entity sensor.p1ib_telegram_received (<class 'homeassistant.components.mqtt.sensor.MqttSensor'>) is using state class 'measurement' which is impossible considering device class ('timestamp') it is using; expected None; Please update your configuration if your entity is manually configured, otherwise create a bug report at https://github.com/home-assistant/core/issues?q=is%3Aopen+is%3Aissue+label%3A%22integration%3A+mqtt%22

Entity sensor.p1ib_reactive_energy_export_q3_q4 (<class 'homeassistant.components.mqtt.sensor.MqttSensor'>) is using state class 'measurement' which is impossible considering device class ('energy') it is using; expected None or one of 'total_increasing', 'total'; Please update your configuration if your entity is manually configured, otherwise create a bug report at https://github.com/home-assistant/core/issues?q=is%3Aopen+is%3Aissue+label%3A%22integration%3A+mqtt%22

Entity sensor.p1ib_reactive_energy_import_q1_q2 (<class 'homeassistant.components.mqtt.sensor.MqttSensor'>) is using state class 'measurement' which is impossible considering device class ('energy') it is using; expected None or one of 'total_increasing', 'total'; Please update your configuration if your entity is manually configured, otherwise create a bug report at https://github.com/home-assistant/core/issues?q=is%3Aopen+is%3Aissue+label%3A%22integration%3A+mqtt%22

johanschelin, 2023-09-21:
And also this

Logger: homeassistant.components.sensor
Source: components/sensor/__init__.py:661
Integration: Sensor (documentation, issues)
First occurred: 19:12:03 (10 occurrences)
Last logged: 19:12:03

Entity sensor.p1ib_reactive_power_minus_l1 (<class 'homeassistant.components.mqtt.sensor.MqttSensor'>) is using native unit of measurement 'kVAr' which is not a valid unit for the device class ('reactive_power') it is using; expected one of ['var']; Please update your configuration if your entity is manually configured, otherwise create a bug report at https://github.com/home-assistant/core/issues?q=is%3Aopen+is%3Aissue+label%3A%22integration%3A+mqtt%22

Entity sensor.p1ib_reactive_power_plus_l2 (<class 'homeassistant.components.mqtt.sensor.MqttSensor'>) is using native unit of measurement 'kVAr' which is not a valid unit for the device class ('reactive_power') it is using; expected one of ['var']; Please update your configuration if your entity is manually configured, otherwise create a bug report at https://github.com/home-assistant/core/issues?q=is%3Aopen+is%3Aissue+label%3A%22integration%3A+mqtt%22

Entity sensor.p1ib_reactive_power_minus_l2 (<class 'homeassistant.components.mqtt.sensor.MqttSensor'>) is using native unit of measurement 'kVAr' which is not a valid unit for the device class ('reactive_power') it is using; expected one of ['var']; Please update your configuration if your entity is manually configured, otherwise create a bug report at https://github.com/home-assistant/core/issues?q=is%3Aopen+is%3Aissue+label%3A%22integration%3A+mqtt%22

Entity sensor.p1ib_reactive_power_plus_l3 (<class 'homeassistant.components.mqtt.sensor.MqttSensor'>) is using native unit of measurement 'kVAr' which is not a valid unit for the device class ('reactive_power') it is using; expected one of ['var']; Please update your configuration if your entity is manually configured, otherwise create a bug report at https://github.com/home-assistant/core/issues?q=is%3Aopen+is%3Aissue+label%3A%22integration%3A+mqtt%22

Entity sensor.p1ib_reactive_power_minus_l3 (<class 'homeassistant.components.mqtt.sensor.MqttSensor'>) is using native unit of measurement 'kVAr' which is not a valid unit for the device class ('reactive_power') it is using; expected one of ['var']; Please update your configuration if your entity is manually configured, otherwise create a bug report at https://github.com/home-assistant/core/issues?q=is%3Aopen+is%3Aissue+label%3A%22integration%3A+mqtt%22

remne, 2023-09-22:
For kVar, It must been added recently (I havent updated my home assistant to latest). Thanks for notifying this. Unit 'var' (or reactive power) have not been available previously.
Will update unit in next-coming dev firmware.

BR,
Andreas

ivik, 2024-01-16:
Hi guys

Besides the errors above I have also found these:

2024-01-16 22:07:17.062 WARNING (MainThread) [homeassistant.components.sensor] Entity sensor.p1ib_reactive_energy_import_q1_q2 (<class 'homeassistant.components.mqtt.sensor.MqttSensor'>) is using native unit of measurement 'kVArh' which is not a valid unit for the device class ('energy') it is using; expected one of ['MWh', 'GJ', 'kWh', 'Wh', 'MJ']; Please update your configuration if your entity is manually configured, otherwise create a bug report at https://github.com/home-assistant/core/issues?q=is%3Aopen+is%3Aissue+label%3A%22integration%3A+mqtt%22

2024-01-16 22:07:17.065 WARNING (MainThread) [homeassistant.components.sensor] Entity sensor.p1ib_reactive_energy_export_q3_q4 (<class 'homeassistant.components.mqtt.sensor.MqttSensor'>) is using native unit of measurement 'kVArh' which is not a valid unit for the device class ('energy') it is using; expected one of ['MWh', 'GJ', 'kWh', 'Wh', 'MJ']; Please update your configuration if your entity is manually configured, otherwise create a bug report at https://github.com/home-assistant/core/issues?q=is%3Aopen+is%3Aissue+label%3A%22integration%3A+mqtt%22

remne, 2024-01-16:
Hi,
These log entries are already in the post above, which is the reason for my comment on not fixing them until the correct and proper unit exists in home assistant :).

Please read post :
https://github.com/remne/p1ib/issues/20#issuecomment-1731024672

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

remne, 2024-01-16:
I actually started to do a fork and fixed the issue in HA, but then I didnt have time for a pull request and everything around that. But will have to take care of it at some point as it seems no one else is doing it.

diff:
https://github.com/home-assistant/core/compare/dev...remne:core:dev

remne, 2024-01-16:
...and I just realized I actually put the unit kVArh in the wrong place... oh well, some day... :)

ivik, 2024-01-16:
Sorry, I was looking for this:  ['MWh', 'GJ', 'kWh', 'Wh', 'MJ'] in the above messages.
And could not see it and thought to add it, but if you already know about it and working on a fix then great.

Thx for a quick reply!

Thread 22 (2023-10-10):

Feature request: Remote restart function

exxoff, 2023-10-10:
I have at times noticed that P1IB sometimes loses the MQTT connection. It's rare but it has happened. A quick reboot solves the issue.

In Home Assistant, I have an automation that notifies me if P1IB hasn't updated in a while. I would like to see a webhook or even a Home Assistant service to restart P1IB in a similar automation.

Cheers!

remne, 2023-10-11:
Hi!
I have got a couple reports about this problem - but I have never been able to reproduce the issue. Until a couple of days ago, when my power provider had a scheduled power outage.

The problem was in the mqtt reconnect logic, which would, in rare occasions, not work as expected. The P1IB needed to be powered on/not restarted for a longer period of time for the error to present itself (which is seldom the case for me as I try new firmwares on the p1ib on my meter from time to time).

I've corrected it in latest dev-firmware (4afb28e).

Other than that, regarding your suggestions, there is a 'telegram last received'-sensor you can check on if no data has been updated in HA for some time. Also there is a http://p1ib.local/restart webservice one can use.
..But I rather see you dont have to add this extra measures, which wont be the case hopefully with latest firmware :).

Regards
Andreas

exxoff, 2023-10-12:
World class, Andreas. I will try the new fw immediately. Thanks!

Closed 2023-10-11.

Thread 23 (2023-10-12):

sensor.p1ib_telegram_received not updating when MQTT Json State is enabled

exxoff, 2023-10-12:
Note! Dev FW 4afb28e

If MQTT JSON State is enabled, the Home Assistant sensor "Telegram Received" becomes "Unknown".

remne, 2023-12-07:
Fixed in firwmare 774b749.

Closed 2023-12-07.

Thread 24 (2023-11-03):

Active power L1-3 (solar) show power

Mika-gbg, 2023-11-03:
Hi,

Recently connected the P1ib as I got a new power meter.
I note that Active power L1-3 (solar) show power even though my solar system is not producing due to evening/dark condtions, see picture.
What could be wrong?

Best regards,
Mika
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

remne, 2023-11-03:
Hi,
It is nothing wrong. The solar sensors are a combination of export and import. It will be negative and positive values depending on if you are exporting or importing power. Right now it is matching your import, if you compare the values.
The only thing that might be wrong is the naming with the word 'solar', :).

remne, 2023-11-03:
The "solar" sensors exists for people that dont want to create a template sensor in Home Assistant for the combination of export and import sensors.

Mika-gbg, 2023-11-03:
Great! Thank you for the quick reply!

Closed 2023-11-03.

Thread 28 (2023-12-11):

Prepare device before using the HAN-port

robbanl, 2023-12-11:
Hello!

I've just bought the device and would like the opportunity to prepare the device before the meeter is switched. Since it's a remote place, I'm planning to setup the wifi connection and then plug it into the meeter once it's switched. There is a risk that they won't be able to turn the HAN-port on the same day, and I might not be there when it's turned on.

So, basically what I'm wondering, can I power the device using a USB-a power source, do my configurations to the wifi, and then shut it down and just have it laying there offline until the meeter is switched and the HAN-port is activated? Think I can leave a note to the people doing the meeter switch to plug it into the new meter :-)

remne, 2023-12-11:
Hi,
Yes its possible to prepare it in beforehand. Just power it by USB. Then under settings there is a "custom SSID"-field, in which you can fill in your remote accesspoint SSID (as you cannot scan for it in your current location).

Regards,
Andreas

robbanl, 2023-12-11:
Just what I was looking for ! Thanks for a superfast reply! I'll close this issue.

Closed 2023-12-11.

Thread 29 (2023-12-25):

WiFi issue

robbanl, 2023-12-25:
Hello!

I run a Unifi network that consists of 3 WiFi access points. They all broadcast 2 networks, 1 for all my IOT devices (2,4ghz only) and one for the rest. When configuring the P1IB unit to connect to my IOT network it didn't work. Doing a scan showed 3 IOT networks and 3 of my regular network. Was unable to get it to connect.

My solution now was to create another separate 2,4 ghz network that was only broadcasted by the outdoor wifi AP. Then it worked just fine.

Just wanted to inform about this issue and if someone else might have the same problem.

remne, 2023-12-25:
Hi,
That is strange. I use Unifi AP:s (AP AC pro) as well, and have the same setup (multiple AP:s, multiple networks on each). It works without any problems here, and I have multiple P1IB:s as well connected to it ;).

P1IB shows each AP with same SSID multiple times, I've done that by purpose in the firmware, but thinking of changing it as it seems to confuse people sometimes (get questions about it frome time to time). However, the ssid itself is just a string so it really doesnt matter. It has no bearing of what AP it will connect to with same SSID.

Regards,
Andreas / Remnetech

robbanl, 2023-12-25:
Yeah, I checked the source and noticed they all had the same ID, so guessed it wasn't an issue :-) Maybe I'm just to tired right now, but I can check it all again tomorrow :)

remne, 2024-01-06:
Were you able to get it to work with your AP:s?

robbanl, 2024-01-06:
Yepp, it works just fine. But still using the new SSID. I haven't been able any more extensive testing, but I'll give it a go in the next couple of weeks. We can close this issue for now :)

Closed 2024-01-06.

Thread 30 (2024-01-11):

RJ12 cable length - Is it possible to extend?

4integration, 2024-01-11:
Hi,

How long is the included cable?
Is it possible to replace the cable e.g. to a 1 m cable? (or 3 m like this https://www.kjell.com/se/produkter/mobilt/fast-telefoni/installation/telekablar/modulkablar/telefonkabel-rj12-till-rj12-3-m-p38406 )

Regards
Joacim

remne, 2024-01-11:
Hi,
The included cable is 50cm. However, if you order from m.nu they can also provide a 150cm cable (write message in the order).

Regards,
Andreas

Closed 2024-01-11.

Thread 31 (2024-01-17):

Red/Blue Blinking LED

LucasHokerberg, 2024-01-17:
I can't reach my P1IB anymore. The problem occurred a few days after I connected it to an HAN switch (as I have new load balancer for my new EV charger). I suspect it might be due to low power, even though the load balancer is working just fine.

In any way, the P1IB LED is blinking blue a few times, then a brief red blink, then back to blue blinking, and so on. What does this pattern mean?

LucasHokerberg, 2024-01-17:
Update: I connected the unit back directly to the energy meter, but still no joy. It blinks blue, then flashes red, then goes back to blinking blue.

remne, 2024-02-10:
Hi,
With HAN-switch I suppose you mean a P1-switch? HAN is the RJ45 standard, which is not supported by the P1IB.

I'm not sure what has happend. But you should contact the m.nu support in first hand.
Issues in github should be used for firmware related issues in first hand.
Will close the issue.
Please mail hello@remne.tech if you cannot solve the issue via m.nu.

marcus-aa, 2024-02-10:
> Hi, With HAN-switch I suppose you mean a P1-switch? HAN is the RJ45 standard, which is not supported by the P1IB.

No, HAN is a general term for the customer port and covers all the different implementations.

The P1 port is one type of HAN. There are HAN-P1, HAN-NVE, HAN-BSI and a british version with zigbee.

remne, 2024-02-10:
OK, Sure :).
Often people refer to the HAN-RJ45 standard when mentioning HAN. Just wanted to clarify.

Closed 2024-02-10.

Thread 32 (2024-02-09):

Reconnect MQTT on lost connection

twDuke, 2024-02-09:
For different reasons my HA server was re-started a couple of times.
On each occasion I had to log in to the p1ib and save settings/restart for it to reconnect.
Is this expected behaviour? Can it be improved?

remne, 2024-02-10:
Hi,
It was a bug that sadly was introduced between some refactoring of the p1ib firmware.
It is fixed in the development firmware since some time back.
However I haven't pushed it as a stable firmware yet.

If you want you can try out the development firmware.

Sorry for the inconvenience.

twDuke, 2024-02-10:
Cool, thanks for the quick reply!

Closed 2024-02-10.

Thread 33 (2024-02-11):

P1ib get disconnected in HomeAssistant if I restarrt HA

4integration, 2024-02-11:
Hi,

If I restart HomeAssistant the sensors gets "unknown" which I think relates that HA loose the state and p1ib just send homeassistant messages at startup (= if I restart p1ib then it works again)

Any configuration possible to get this smoother?

/ Joacim

4integration, 2024-02-12:
Duplicate? https://github.com/remne/p1ib/issues/32

remne, 2024-02-27:
Yes, duplicated and fixed in latest firmware.

Closed 2024-02-27.

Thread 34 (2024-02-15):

Invalid state message warnings in HomeAssistant

andersjohansson3, 2024-02-15:
Logger: homeassistant.components.mqtt.sensor
Source: components/mqtt/sensor.py:245
Integration: MQTT (documentation, issues)
First occurred: 19:08:38 (23 occurrences)
Last logged: 19:08:59

Invalid state message `{
    "p1ib_clock_date": null,
    "p1ib_hourly_active_import_q1_q4": 5213.196,
    "p1ib_hourly_active_export_q2_q3": 0,
    "p1ib_hourly_reactive_import_q1_q2": 0.955,
    "p1ib_hourly_reactive_export_q3_q4": 418.856,
    "p1ib_active_power_plus_q1_q4": 4.164,
    "p1ib_active_power_minus_q2_q3": 0,
    "p1ib_reactive_power_plus_q1_q2": 0,
    "p1ib_reactive_power_minus_q3_q4": 0.303,
    "p1ib_active_power_plus_l1": 1.3,
    "p1ib_active_power_minus_l1": 0,
    "p1ib_active_power_plus_l2": 1.342,
    "p1ib_active_power_minus_l2": 0,
    "p1ib_active_power_plus_l3": 1.522,
    "p1ib_active_power_minus_l3": 0,
    "p1ib_reactive_power_plus_l1": 0,
    "p1ib_reactive_power_minus_l1": 0.224,
    "p1ib_reactive_power_plus_l2": 0.052,
    "p1ib_reactive_power_minus_l2": 0,
    "p1ib_reactive_power_plus_l3": 0,
    "p1ib_reactive_power_minus_l3": 0.131,
    "p1ib_voltage_l1": 231.2,
    "p1ib_voltage_l2": 232,
    "p1ib_voltage_l3": 233.5,
    "p1ib_current_l1": 5.7,
    "p1ib_current_l2": 5.7,
    "p1ib_current_l3": 6.6,
    "p1ib_firmware": "e9309dd",
    "p1ib_update_available": "",
    "p1ib_import_export_l1": null,
    "p1ib_import_export_l2": null,
    "p1ib_import_export_l3": "1.522",
    "p1ib_import_export": null,
    "p1ib_rssi": "-78",
    "p1ib_meter": "KAM5",
    "p1ib_mac": "********",
    "p1ib_telegrams_crc_ok": 173538,
    "p1ib_ip": "**.**.**.**"
}`
from 'power/p1ib/sensor_state'

andersjohansson3, 2024-03-02:
So, this continues to be an issue, and it's really filling up my warning logs:

Logger: homeassistant.components.mqtt.sensor
Source: components/mqtt/sensor.py:245
Integration: MQTT
First occurred: 1 mars 2024 kl. 23:04:11 (**36028 occurrences**)
Last logged: 09:10:42

Invalid state message `'{"p1ib_clock_date":null,"p1ib_hourly_active_import_q1_q4":5834.307,"p1ib_hourly_active_export_q2_q3":0,"p1ib_hourly_reactive_import_q1_q2":1.034,"p1ib_hourly_reactive_export_q3_q4":494.37,"p1ib_active_power_plus_q1_q4":0.869,"p1ib_active_power_minus_q2_q3":0,"p1ib_reactive_power_plus_q1_q2":0,"p1ib_reactive_power_minus_q3_q4":0.181,"p1ib_active_power_plus_l1":0.288,"p1ib_active_power_minus_l1":0,"p1ib_active_power_plus_l2":0.387,"p1ib_active_power_minus_l2":0,"p1ib_active_power_plus_l3":0.194,"p1ib_active_power_minus_l3":0,"p1ib_reactive_power_plus_l1":0,"p1ib_reactive_power_minus_l1":0.171,"p1ib_reactive_power_plus_l2":0.053,"p1ib_reactive_power_minus_l2":0,"p1ib_reactive_power_plus_l3":0,"p1ib_reactive_power_minus_l3":0.063,"p1ib_voltage_l1":230.2,"p1ib_voltage_l2":230.3,"p1ib_voltage_l3":231.6,"p1ib_current_l1":1.5,"p1ib_current_l2":1.7,"p1ib_current_l3":1.3,"p1ib_firmware":"aae1e85","p1ib_update_available":"","p1ib_import_export_l1":null,"p1ib_import_export_l2":"0.387","p1ib_import_export_l3":null,"p1ib_import_export":null,"p1ib_rssi":null,"p1ib_meter":"KAM5","p1ib_mac":"********","p1ib_ip":"**.**.**.**","p1ib_telegrams_crc_ok":342309}' `
from 'power/p1ib/sensor_state'

There are a bunch of null values in the warning logs, could it be those that are causing the issue?

remne, 2024-03-08:
Hi,
Yes, it should not be null values.
What firmware are you running? and what meter?

I will take a look at this issue during the weekend, sorry for the late reply.

For now you could try to disable JSON payload in the p1ib settings, in that way it will only send mqtt messages on sensors that have new data.

Regards,
Andreas

andersjohansson3, 2024-03-08:
I have an Electric Meter "KAM5", Meter Mode "Mode-D" and running latest firmware, aae1e85.
I'll try with setting MQTT Json state to false.

remne, 2024-03-08:
Yes KAM5, but what physical meter is it? A Kamstrup OMNIA?

andersjohansson3, 2024-03-08:
Just realized i needed to add that 😊
Yes, it's Göteborg Energis Kamstrup Omnia e-meter

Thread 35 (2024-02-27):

Updated HA and P1ib - not working

4integration, 2024-02-27:
Hi,

Updated HA Core to 2024.2.4 and restarted p1ib, no sensors gets `unavailable`.
Updated p1ib to latest stable (20240212), I see 30+ MQTT messages being sent to topic like `homeassistant/sensor/p1ib/p1ib_h_active_imp_q1_q4/config`

All sensors are still `unavailable`

Also noted in HA logs

```
2024-02-27 19:24:46.409 WARNING (MainThread) [homeassistant.components.sensor] Entity sensor.p1ib_reactive_power_minus_l3 (<class 'homeassistant.components.mqtt.sensor.MqttSensor'>) is using native unit of measurement 'kVAr' which is not a valid unit for the device class ('reactive_power') it is using; expected one of ['var']; Please update your configuration if your entity is manually configured, otherwise create a bug report at https://github.com/home-assistant/core/issues?q=is%3Aopen+is%3Aissue+label%3A%22integration%3A+mqtt%22
2024-02-27 19:24:46.410 WARNING (MainThread) [homeassistant.components.sensor] Entity sensor.p1ib_reactive_power_plus_l3 (<class 'homeassistant.components.mqtt.sensor.MqttSensor'>) is using native unit of measurement 'kVAr' which is not a valid unit for the device class ('reactive_power') it is using; expected one of ['var']; Please update your configuration if your entity is manually configured, otherwise create a bug report at https://github.com/home-assistant/core/issues?q=is%3Aopen+is%3Aissue+label%3A%22integration%3A+mqtt%22
2024-02-27 19:24:46.417 WARNING (MainThread) [homeassistant.components.sensor] Entity sensor.p1ib_reactive_power_minus_l2 (<class 'homeassistant.components.mqtt.sensor.MqttSensor'>) is using native unit of measurement 'kVAr' which is not a valid unit for the device class ('reactive_power') it is using; expected one of ['var']; Please update your configuration if your entity is manually configured, otherwise create a bug report at https://github.com/home-assistant/core/issues?q=is%3Aopen+is%3Aissue+label%3A%22integration%3A+mqtt%22
2024-02-27 19:24:46.418 WARNING (MainThread) [homeassistant.components.sensor] Entity sensor.p1ib_reactive_power_plus_l2 (<class 'homeassistant.components.mqtt.sensor.MqttSensor'>) is using native unit of measurement 'kVAr' which is not a valid unit for the device class ('reactive_power') it is using; expected one of ['var']; Please update your configuration if your entity is manually configured, otherwise create a bug report at https://github.com/home-assistant/core/issues?q=is%3Aopen+is%3Aissue+label%3A%22integration%3A+mqtt%22
2024-02-27 19:24:46.419 WARNING (MainThread) [homeassistant.components.sensor] Entity sensor.p1ib_reactive_power_minus_l1 (<class 'homeassistant.components.mqtt.sensor.MqttSensor'>) is using native unit of measurement 'kVAr' which is not a valid unit for the device class ('reactive_power') it is using; expected one of ['var']; Please update your configuration if your entity is manually configured, otherwise create a bug report at https://github.com/home-assistant/core/issues?q=is%3Aopen+is%3Aissue+label%3A%22integration%3A+mqtt%22
2024-02-27 19:24:46.420 WARNING (MainThread) [homeassistant.components.sensor] Entity sensor.p1ib_reactive_power_plus_l1 (<class 'homeassistant.components.mqtt.sensor.MqttSensor'>) is using native unit of measurement 'kVAr' which is not a valid unit for the device class ('reactive_power') it is using; expected one of ['var']; Please update your configuration if your entity is manually configured, otherwise create a bug report at https://github.com/home-assistant/core/issues?q=is%3Aopen+is%3Aissue+label%3A%22integration%3A+mqtt%22
2024-02-27 19:24:46.424 WARNING (MainThread) [homeassistant.components.sensor] Entity sensor.p1ib_reactive_power_minus_q3_q4 (<class 'homeassistant.components.mqtt.sensor.MqttSensor'>) is using native unit of measurement 'kVAr' which is not a valid unit for the device class ('reactive_power') it is using; expected one of ['var']; Please update your configuration if your entity is manually configured, otherwise create a bug report at https://github.com/home-assistant/core/issues?q=is%3Aopen+is%3Aissue+label%3A%22integration%3A+mqtt%22
2024-02-27 19:24:46.426 WARNING (MainThread) [homeassistant.components.sensor] Entity sensor.p1ib_reactive_power_plus_q1_q2 (<class 'homeassistant.components.mqtt.sensor.MqttSensor'>) is using native unit of measurement 'kVAr' which is not a valid unit for the device class ('reactive_power') it is using; expected one of ['var']; Please update your configuration if your entity is manually configured, otherwise create a bug report at https://github.com/home-assistant/core/issues?q=is%3Aopen+is%3Aissue+label%3A%22integration%3A+mqtt%22
2024-02-27 19:24:46.433 WARNING (MainThread) [homeassistant.components.sensor] Entity sensor.p1ib_reactive_energy_export_q3_q4 (<class 'homeassistant.components.mqtt.sensor.MqttSensor'>) is using native unit of measurement 'kVArh' which is not a valid unit for the device class ('energy') it is using; expected one of ['Wh', 'kWh', 'GJ', 'MJ', 'MWh']; Please update your configuration if your entity is manually configured, otherwise create a bug report at https://github.com/home-assistant/core/issues?q=is%3Aopen+is%3Aissue+label%3A%22integration%3A+mqtt%22
2024-02-27 19:24:46.435 WARNING (MainThread) [homeassistant.components.sensor] Entity sensor.p1ib_reactive_energy_import_q1_q2 (<class 'homeassistant.components.mqtt.sensor.MqttSensor'>) is using native unit of measurement 'kVArh' which is not a valid unit for the device class ('energy') it is using; expected one of ['Wh', 'kWh', 'GJ', 'MJ', 'MWh']; Please update your configuration if your entity is manually configured, otherwise create a bug report at https://github.com/home-assistant/core/issues?q=is%3Aopen+is%3Aissue+label%3A%22integration%3A+mqtt%22

```

remne, 2024-02-27:
Probably case is HA changed how entities are named, depending on your previous version of HA.
https://github.com/home-assistant/core/pull/95159
In HA, go to 'settings -> device & services" -> devices, scroll to p1ib device and take a look.
If you have duplicated sensors, remove the device (... icon and remove device) then restart p1ib for new registration to take place.

Regarding reactive energy/power warnings. This warning is already reported in https://github.com/remne/p1ib/issues/20, and is not fixable due to HA does not support units that define reactive energy and correct for reactive power.

4integration, 2024-02-28:
Actually tried to remove p1ib device yesterday but no success.
Did it again and restarted p1ib but for some reason I cannot access http://p1ib.local no more :(

I saw it registers in my router's device list (Ubiquiti DreamMachine) and accessing IP doesn't work either.
But then it disappeared again and not showing up what it seems....hmm

4integration, 2024-02-29:
Got it working again

Closed 2024-02-29.

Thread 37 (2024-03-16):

Home Assistant loose P1ib EVERY time HA is restarted (Unavailable entities)

4integration, 2024-03-16:
Hi,

**Every time** I restart Home Assistant it looses P1ib entities and they became "Unavailable".
Restarting P1ib doesn't help but I can see the entities flick for <1sec.
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

Removing P1ib device and entities, restarting HA and P1ib several times can make it work again.
Very annoying!

"P1IB Telegram received" is received every ~10 sec

I can see MQTT messages being sent and device/entities gets created but Unavailable

HA Core: 2024.3.1
HA: Supervisor: 2024.03.0
HA Operating System: 12.1
HA Frontend: 20240307.0

P1ib Build: aae1e85
P1ib Build Date: 20240212

4integration, 2024-03-16:
Even after deleting the device I removed all `p1ib` from `core.entity_registry` and `core.device_registry` and rebooted before rebooted P1ib...still no success

remne, 2024-03-16:
Hi,
I can see why this is annoying.
However, I'm not so sure this is a problem in p1ib, but something rather in your environment.

But to be sure, lets troubleshoot a bit and see if we can figure it out.

Some background: P1IB send a registration message at each connection to the mqtt broker for each sensor, which contains information about the sensor and its state topic. It also enables availability on each sensor. The availiability is based on the 'will'-message registered during connection to the broker.
This state sends 'online' during connection, and sends the will message 'offline' (automatically sent by the broker if connection is lost or timed out).
If HA receives 'offline' it will set all sensors connected to it to unavailable.
Note, this is the case for all sensors - except the timeout sensor.

So that is how the HA/MQTT messaging works for sensor availability.

If you start mosquitto_sub with parameter -t '#' and -v ( to subscribe to all topics), you can verify this.
After you have started mosquitto_sub, then restart your p1ib. Then you should see something like this:
"
p1ib_a0a3b3409e18/state offline
p1ib_a0a3b3409e18/state online
homeassistant/sensor/p1ib/<sensor>/config {...}
homeassistant/sensor/p1ib/<sensor>/config {...}  ....and so forth for each sensor.
"

And then a few seconds later (depending on your json state setting i p1ib ) you will receive values for each sensor or a json message with all sensor values - if your p1ib is connected to your power meter and receives telegrams.
These messages should occur with your power meters telegram interval (most likely each 10s)

If this is the case, then everything works as expected from p1ib and the issue is in your environment.

You can manually try the availability feature by simulating that the p1ib is online or offline by excuting:
$ mosquitto_pub -t "p1ib_a0a3b3409e18/state" -m "offline" -h <broker-ip>
$ mosquitto_pub -t "p1ib_a0a3b3409e18/state" -m "online" -h <broker-ip>
Replace the p1ib mac with your mac.

If your p1ib doesnt send MQTT messages as described above, then please post your MQTT messaging from mosquitto_sub here and also your p1ib settings so that we can try to troubleshoot further.

Regards,
Andreas

4integration, 2024-03-17:
Hi Andreas,

P1ib do send MQTT messages (both on `homeassistant/#` and `p1ib/#`), I however use RabbitMQ and sniff topics with MQTT.fx.

Now I disabled MQTT in P1ib but can still see some messages @ `homeassistant/status` with `online` or `offline` even though disabled but reflects the status of HA.
Removed entities as described above in HA, and rebooted HA.
P1ib reports `online`, enable MQTT.
Then ~35 messages appears in `homeassistant/#` and then it starts publishing on `p1ib/#`

So agree that P1ib publish messages and by the latest approach in this post, it started to work again.
But feels like the combination of HA and P1ib isn't flawless
Maybe HA gets confused when P1ib sends messages while HA restarts.

remne, 2024-03-17:
Hi,
"homeassistant/status" is not published by P1IB. It's HA that publishes messsages on that topic. So it doesnt have anything to do with P1IB.

If there was an issue with how P1IB sends messages to HA, there would be a lot more people than you that have the same issue. So I'm still leaning against that the issue is still in your environment at this point.

Do you have retained messages disabled or will message support in your mqtt broker?  Both needs to be enabled.
To verify retained messages enabled: do you get latest published data by the p1ib topics when you connect and subscribe with topic # (all topics) with your sniffer?
You should see a 'p1ib_mac/state online' if P1IB is running. Also you would see the different value of each sensor.
Normally this is enabled by default in mosquitto's broker, which is of course is needed. I dont know how RabbitMQ default config looks like.
Otherwhise if HA subscribes to topics later than when any of the MQTT devices that communicate with HA sends its auto discovery information and its availiability state (like P1IB do) HA will miss it and availability will most likely not change from its initial "unavailable"-state.

To verify 'will' message enabled: In your mqtt sniffer, make sure that, when P1IB is going from MQTT state connected to not connected (for instance, you plug P1IB out). A message should be published to p1ib_mac/state with message 'offline' after a few seconds (or whatever timeout value your broker have configured).

If you can send me your MQTT broker configuration, P1IB settings and MQTT messages from when you restart your HA instance while P1IB is running, then maybe I can figure out the issue you have.
Other than that, I'm not sure what I can do to help you out more.

Regards,
Andreas

4integration, 2024-03-17:
Thanks @remne , looked a bit deeper and guess it is time for me to switch to Mosquitto
I do not think messages are retained, should be configurable.
Since I have had thoughts of switching to Mosquitto....

Saw from [HA](https://www.home-assistant.io/integrations/mqtt/)

> Neither ActiveMQ MQTT broker nor the RabbitMQ MQTT Plugin are supported, use a known working broker like Mosquitto instead. There are [at least two](https://issues.apache.org/jira/browse/AMQ-6360) [issues](https://issues.apache.org/jira/browse/AMQ-6575) with the ActiveMQ MQTT broker which break MQTT message retention.

So I start in with that.

4integration, 2024-03-17:
@remne thanks for your help

Now switched to Mosquitto (pretty easy) and it seems to be working fine :) (at least after one HA reboot)

My config:

```
joacim@server:~$ more /data/disk1/mosquitto/config/mosquitto.conf
allow_anonymous false
listener 1883
listener 9001
protocol websockets

password_file /mosquitto/config/pwfile

persistence true
persistence_file mosquitto.db
persistence_location /mosquitto/data/
```

Bonus is to lower the footprint of MQTT broker even though RabbitMQ wasn't that demanding :)

remne, 2024-03-17:
Glad to hear it worked out!

Good to know that RabbitMQ (currently) have issues with retained messages.

Regards,
Andreas

Closed 2024-03-17.

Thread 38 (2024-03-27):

Rate limit data sent to MQTT?

seaside1, 2024-03-27:
Is it possible to put some limit on the update frequency on the messages being sent to mqtt?
For me it should be enough to get the state posted every 10th second or so.

remne, 2024-03-27:
Hi,
No there are no setting for exactly that. However, you can enable reduced mode and set a threshold on your sensors to decrease the amount of data that is sent over MQTT.
You can also disabled certain measurements if your not interested in them to reduce data throughput even more.

Regards,
Andreas

seaside1, 2024-04-03:
Would it be possible to add a setting with a  certain update interval time?
Maybe more peoples are interested in this setting.

remne, 2024-04-08:
I will add it to the future feature list.

Regards,
Andreas

bjorne, 2024-10-06:
I second this request. The Home Assistant recorder database becomes very big with the high frequency of reporting. 10s, 30s or 60s would be more appropriate for my use-case.

I only rarely require more frequent updated values and it would be great if p1ib's own UI would still be quickly refreshed even if MQTT when was updated with lower frequency.

remne, 2024-10-09:
You have the option to enable "reduced mode", then you can finetune the bandwidth based on what you are interested in.
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

bjorne, 2024-10-09:
The hysteresis threshold will delay the update until a large enough difference has been observed, correct? It might work decently for the measures which strictly increase, e.g. kWh, but ideally I would like the updates to be recorded regularly regardless if the change is small, for example during low usage periods. For momentary values such as kW or V it seems less easy to find a reasonable threshold to give the right update frequency.

Being able to control the frequency directly just seems like a better lever for my use-case, since it directly translates into number of recordings (and thus data size) across all measures equally.

bjorne, 2024-11-11:
@remne I have now given reduced data mode a shot and have some feedback. Overall it doesn’t seem to match what I want well: all (or a subset of) values af a slower frequency.

First, some UI feedback: I need to press save & restart many times before anything happens. (This is on Firefox iOS - haven’t debugged on a computer yet)

Second, several key measures seem to be missing from the list in reduced data mode. For example, `p1ib_h_active_imp_q1_q4`. So when I enable this mode these values simply stop updating. Why are they not included?

If this mode should work well for me it would probably need to work something more like this:

* I enable reduced data mode
* I enable hysteresis on some measure. For example, something like `p1ib_h_active_imp_q1_q4` with 0.01 kWh. (But maybe exposing the telegram number and hysteresis of 10 would work even better)
* When this threshold is met, a complete state update with all (selected?) measures is propagated to MQTT

But maybe a simple rate limiting would be simpler…

Let me know if I’m missing something.

Closed 2024-04-08.

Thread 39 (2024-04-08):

What rj12 cable to use

seaside1, 2024-04-08:
Hi!

I bought a 3 m standard rj12 cable for the p1ib. But it does not seem to work.

https://www.kjell.com/se/produkter/mobilt/fast-telefoni/installation/telekablar/modulkablar/telefonkabel-rj12-till-rj12-3-m-p38406

Is there any specific layout of the cable?

marcus-aa, 2024-04-08:
Telephone cables come in 2 variants, straight or crossed. For phones it does not normally matter, but as the P1 port is assymetric it has to be the same that the designer of the interface intended.

Unfortunately, different P1-readers have chosen differently so some readers need one type and some the other.

You can probably see that the original cable is different from the new one by holding the plugs side by side and comparing.

I have a complete toolkit for crimping the connectors myself, but that is no help to you... Didn't expect to have any more use from analog telephone tools, but good to have now.

seaside1, 2024-04-08:
Can you point me to a cable that works? Looking at the cable in seems like it is crossed. Most han-meters seem to use straight connection (like the one I have).
Would it work to use a rj12 to rj12 adapter and attach the short cable (crossed) to a longer straight (I guess result would be crossed).

labanskoller, 2024-04-24:
I also realized this the hard way. I got a correct (but quite short) cable when I bought my P1B via m.nu. Didn't you get one, @seaside1?
If you have a crossover cable you can extend it with a longer straight cable with such an adapter as you describe. I have successfully patched my smart meter around 10 meters using normal RJ45 sockets used for Ethernet, and then attached the P1B the last ½ meter with the crossover cable.

I think it should be clearly documented that P1B requires a crossover cable, as many other devices (SlimmeLezer for instance) use straight cables and that's what's easy to find e.g. at Kjell&Co.

seaside1, 2024-05-21:
Missed to answer this. Yes I bought a straight cable and used an rj12 to rj12 adapter.
Maybe would be good to document this with the retailers so you don't end up with a new straight cable that is not working

remne, 2024-05-22:
Hi,
@seaside1  good to hear that your issue was solved.
As already mentioned the cable for P1IB is a cross over cable.

Normally a longer cable than 0.5m is not needed, as the P1IB device is supposed to be placed a long side the power meter, inside the meter cabinet. If one needs better Wi-Fi reception the P1IB-ext product is meant to fill that gap.

I do however also provide 1.5m cables when ordering from remne.tech if one chooses it. M.nu also provides this free of extra charge (at least at the time of writing) if one asks for it.

There are a couple of things that one should think of when using their own cable. One is that me or m.nu cannot guarentee the function of the p1ib device, or what it could do with the device over time (think in the line of increased risk of esd, voltage drop, bit error during transmission, reflections/ringing in transmission lines, damage to the p1-interface of the p1ib and/or the power meter for instance depending on placement.
Then there is also the question of product warranty if one uses their own (and possible own manufactured) cable.

Also I dont know how many hours I've spent in support mails, just to realize that the customer manufactured their own cable with bad crimping or didnt realize that the cable is cross over connected. :)

So from my stand point, I'd rather not have people experiment too much with their own cables. But on the other hand I know people will do it anyways, so its better to support than to shut them off :). I do modification on products as well.
I will update the product description on remne.tech regarding the cable is cross over.

Please close the github ticket if you feel that your issue have been solved.

Cheers,
Andreas / Remnetech

Closed 2024-09-17.

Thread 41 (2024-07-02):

Force update of mqtt values in Home Assistant.

DavidLennartsson, 2024-07-02:
I have other sensors in home assistant that are calculated based on the current sensors in p1ib.
Sometimes the amperage draw is almost static for some time, that means that the calculations won't be updated until the value actually changes.

Could you add a "force_update" option so that the values are updated in Home Assistant even if they values haven't changed?
https://www.home-assistant.io/integrations/sensor.mqtt/

remne, 2024-09-17:
Hi David,
I'll add it to the feature list!

remne, 2024-09-20:
force_update added in latest dev firmware

example:
homeassistant/sensor/p1ib/p1ib_h_active_imp_q1_q4/config {"unique_id":"p1ib_hourly_active_import_q1_q4","name":"Active energy import Q1 Q4","stat_t":"p1ib/sensor_state","device_class":"energy","unit_of_measurement":"kWh","state_class":"total","value_template":"{{ value_json['p1ib_hourly_active_import_q1_q4'] }}","device":{"identifiers":["p1ib_b0b21ca00a68"],"manufacturer":"Remne Technologies AB","model":"P1 Interface Bridge","sw_version":"fdce72e","name":"P1IB","configuration_url":"http://192.168.0.232","connections":[["mac","b0:b2:1c:a0:0a:68"]]},"availability":[{"topic":"p1ib_b0b21ca00a68/state"}],"availability_mode":"latest","force_update":true}

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

Please verify and give feedback if possible.

Regards,
Andreas

Closed 2024-11-23.

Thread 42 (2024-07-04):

Device not booting up on active HAN port

mijak99, 2024-07-04:
Hi,

I have just received my device (https://www.m.nu/sensorer-wifi/elmatare-for-p1-han-port-med-wifi)

Connected it to a Kaifa MA304H4D with activated HAN-port, but nothing happens. The LED does not light up.
For clarity:
-  I am using the original crossed RJ12 cable that was supplied from m.nu
-  The HAN port indicator on the meter display is active, indicating the HAN port is active. Have double-checked with the supplier too.
- Edit: Tried powering the device via the USB port, which works fine. But does not seem to receive any data.

Since the MA304 is listed as a supported meter, I am assuming something is off?
Any ideas on how I can troubleshoot this issue?

If this is the wrong place to ask, or if more information is needed, let me know.

remne, 2024-07-10:
Hi,

MA304H4D is a M-Bus meter, and not P1-meter as far as I know. P1IB only works with MA304 meters that have a P1 interface.
If you take a look at the meter, there is probably a "M-Bus"-label somewhere on it, indicating its not a P1 meter, instead it uses HAN-NVE (Norwegian standard).

Regards,
Andreas

mijak99, 2024-07-11:
Thanks for the response.   FYI, I can confirm that there is an M-bus marking on the meter.

I thought that the Norwegian standard was using RJ45, but this one has an RJ12.

Anyways, thanks for getting back to me and resolving the issue.

Closed 2024-09-08.

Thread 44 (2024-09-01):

Problem finding wifi networks

henca, 2024-09-01:
When pressing "SCAN" to find available WiFi networks SSID my laptop gets disconnected from the P1IB WiFi network. When reconnecting to the P1IB network the list of available SSID is once again empty and pressing "SCAN" again gives the same result with disconnected from P1IB WiFi network. I am currently on firmware aae1e85 built 2024-02-12.

henca, 2024-09-01:
Problem solved! By enabling advanced settings I was able to enter the SSID to connect to. Sorry for the noise!

Closed 2024-09-08.

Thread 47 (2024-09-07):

MQTT: topic prefix

merbanan, 2024-09-07:
I have 3 meters and readers sending data to one mqtt server. It would be nice to get the prefix in the message. One could then filter directly on the message content instead of using a lookup on the mac-address.

remne, 2024-09-07:
There is an option to have both the MAC and/or an custom prefix on the topic. It should be sufficient to be able to differentiate between the meters.

Regards,
Andreas

merbanan, 2024-09-07:
Yes. It works fine but it would be nice to use the prefix as id directly instead of do a lookup of the topic or mac. I send everything to influx and it would be nice if the json is as complete as possible. If you only have 1 meter it doesnt matter but I have 3 of them.

remne, 2024-09-13:
What do you mean with id? You mean the prefix should be part of the json object?

merbanan, 2024-09-13:
Right now the json objects are passed around in the data pipeline I use, thus the topic is not passed along with it. So I have to do a lookup on the mac address and then map based on that.

Ideally one should be able to configure p1ib to set a key to a custom value. This would remove the need to do the lookup, which would be nice.

remne, 2024-09-20:
p1ibeth/p1ib/sensor_state:
{   'p1ib_active_power_minus_l1': 0,
    'p1ib_active_power_minus_l2': 0,
    'p1ib_active_power_minus_l3': 0,
    'p1ib_active_power_minus_q2_q3': 0,
    'p1ib_active_power_plus_l1': 1.028,
    'p1ib_active_power_plus_l2': 0.494,
    'p1ib_active_power_plus_l3': 0.047,
    'p1ib_active_power_plus_q1_q4': 1.557,
    'p1ib_current_l1': 4.4,
    'p1ib_current_l2': 2.9,
    'p1ib_current_l3': 0.5,
    'p1ib_custom_id': 'some_custom_id',
    'p1ib_eth_mac': 'b0b21ca25457',
    'p1ib_firmware': 'fdce72e',
    'p1ib_hourly_active_export_q2_q3': 12370.641,
    'p1ib_hourly_active_import_q1_q4': 74714.898,
    'p1ib_hourly_reactive_export_q3_q4': 10871.154,
    'p1ib_hourly_reactive_import_q1_q2': 7610.008,
    'p1ib_import_export': 1.557,
    'p1ib_import_export_l1': 1.028,
    'p1ib_import_export_l2': 0.494,
    'p1ib_import_export_l3': 0.047,
    'p1ib_ip': '192.168.0.218',
    'p1ib_meter': 'Aidon',
    'p1ib_reactive_power_minus_l1': 0.195,
    'p1ib_reactive_power_minus_l2': 0.49,
    'p1ib_reactive_power_minus_l3': 0.12,
    'p1ib_reactive_power_minus_q3_q4': 0.809,
    'p1ib_reactive_power_plus_l1': 0,
    'p1ib_reactive_power_plus_l2': 0,
    'p1ib_reactive_power_plus_l3': 0,
    'p1ib_reactive_power_plus_q1_q2': 0,
    'p1ib_rssi': '0',
    'p1ib_telegrams_crc_ok': 5,
    'p1ib_voltage_l1': 235.7,
    'p1ib_voltage_l2': 236.4,
    'p1ib_voltage_l3': 236.8,
    'p1ib_wifi_mac': 'b0b21ca25454'}
}

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

Added a custom id field, which results in key/value id: <string> added to the json payload.

Available in latest dev firmware.

Please verify and give feedback if possible.

Regard,
Andreas

remne, 2024-11-23:
Closing the issue as no feedback was given.

Closed 2024-11-23.

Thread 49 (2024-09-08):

MQTT: kWh readings missing

merbanan, 2024-09-08:
The readings from p1ib/sensor_state is missing meter kWh if I can parse things correctly.

    "1-0:1.8.0": [
      755313,
      755313.12,
      755313.12,
      755313.24,
      755313.36,
      755313.48,
      755313.48,
      755313.6,
      755313.72,
      755313.72
    ],
    "1-0:2.8.0": [
      25996.92,
      25996.92,
      25996.92,
      25996.92,
      25996.92,
      25996.92,
      25996.92,
      25996.92,
      25996.92,
      25996.92
    ],

{
  "p1ib_clock_date": null,
  "p1ib_hourly_active_import_q1_q4": 6294.273,
  "p1ib_hourly_active_export_q2_q3": 216.641,
  "p1ib_hourly_reactive_import_q1_q2": 0.63,
  "p1ib_hourly_reactive_export_q3_q4": 1234.576,
  "p1ib_active_power_plus_q1_q4": 0,
  "p1ib_active_power_minus_q2_q3": 0.012,
  "p1ib_reactive_power_plus_q1_q2": 0,
  "p1ib_reactive_power_minus_q3_q4": 0.139,
  "p1ib_active_power_plus_l1": 0.005,
  "p1ib_active_power_plus_l2": 0.025,
  "p1ib_active_power_plus_l3": 0,
  "p1ib_active_power_minus_l1": 0,
  "p1ib_active_power_minus_l2": 0,
  "p1ib_active_power_minus_l3": 0.043,
  "p1ib_reactive_power_plus_l1": 0,
  "p1ib_reactive_power_plus_l2": 0,
  "p1ib_reactive_power_plus_l3": 0,
  "p1ib_reactive_power_minus_l1": 0.045,
  "p1ib_reactive_power_minus_l2": 0.055,
  "p1ib_reactive_power_minus_l3": 0.039,
  "p1ib_voltage_l1": 230.3,
  "p1ib_voltage_l2": 229.8,
  "p1ib_voltage_l3": 231.5,
  "p1ib_current_l1": 0.2,
  "p1ib_current_l2": 0.3,
  "p1ib_current_l3": 0.2,
  "p1ib_import_export_l1": 0.005,
  "p1ib_import_export_l2": 0.025,
  "p1ib_import_export_l3": -0.043,
  "p1ib_import_export": -0.012,
  "p1ib_rssi": "0",
  "p1ib_telegrams_crc_ok": 169,
  "p1ib_meter": "ELL5\\253876812_B",
  "p1ib_mac": "b0b21ca25630",
  "p1ib_firmware": "f934567",
  "p1ib_update_available": "",
  "p1ib_ip": "0.0.0.0"
}

remne, 2024-09-08:
"p1ib_hourly_active_import_q1_q4": 6294.273,
"p1ib_hourly_active_export_q2_q3": 216.641,
is the energy measurements import and export (obis code 1.8.0 and 2.8.0).
However I think you might mix the /meterData output and the MQTT messages between your P1IB devices? :)

merbanan, 2024-09-08:
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

vs

```
{
  "p1ib_clock_date": null,
  "p1ib_hourly_active_import_q1_q4": 6295.953,
  "p1ib_hourly_active_export_q2_q3": 216.642,
  "p1ib_hourly_reactive_import_q1_q2": 0.63,
  "p1ib_hourly_reactive_export_q3_q4": 1235.146,
  "p1ib_active_power_plus_q1_q4": 0.587,
  "p1ib_active_power_minus_q2_q3": 0,
  "p1ib_reactive_power_plus_q1_q2": 0,
  "p1ib_reactive_power_minus_q3_q4": 0.147,
  "p1ib_active_power_plus_l1": 0.207,
  "p1ib_active_power_plus_l2": 0.218,
  "p1ib_active_power_plus_l3": 0.162,
  "p1ib_active_power_minus_l1": 0,
  "p1ib_active_power_minus_l2": 0,
  "p1ib_active_power_minus_l3": 0,
  "p1ib_reactive_power_plus_l1": 0,
  "p1ib_reactive_power_plus_l2": 0,
  "p1ib_reactive_power_plus_l3": 0,
  "p1ib_reactive_power_minus_l1": 0.047,
  "p1ib_reactive_power_minus_l2": 0.05,
  "p1ib_reactive_power_minus_l3": 0.05,
  "p1ib_voltage_l1": 232.1,
  "p1ib_voltage_l2": 231.3,
  "p1ib_voltage_l3": 234,
  "p1ib_current_l1": 0.9,
  "p1ib_current_l2": 0.9,
  "p1ib_current_l3": 0.7,
  "p1ib_import_export_l1": 0.207,
  "p1ib_import_export_l2": 0.218,
  "p1ib_import_export_l3": 0.162,
  "p1ib_import_export": 0.587,
  "p1ib_rssi": "0",
  "p1ib_telegrams_crc_ok": 1709,
  "p1ib_meter": "ELL5\\253876812_B",
  "p1ib_mac": "b0b21ca25630",
  "p1ib_firmware": "f934567",
  "p1ib_update_available": "No",
  "p1ib_ip": "0.0.0.0"
}
```
But I think I see what the issue is. If I add the transformer scaling factor I get somewhat the correct reading. As can be seen in the output I am running the latest stable release.

6295.953*120 = 755514.36

But I also see that the mac address miss-matches by 3.

merbanan, 2024-09-09:
With a58dff6 this issue is fixed.

The mac address is still different compared to the ui though.

remne, 2024-09-10:
The MAC in the json message is actually the Wi-Fi MAC. The ethernet MAC is not added in the json message in the current firmware, which might be a bit confusing.
I will add the ethernet mac as well in the next firmware.

Closed 2024-09-09.

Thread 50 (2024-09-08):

Low resolution on current/power

merbanan, 2024-09-08:
I get low resolution on these values, I do have 120/80 in transformer factor. Is that the reason for the low resolution?

merbanan, 2024-09-09:
The low resolution seems to be what the meter is delivering. The current is bad but power is somewhat ok.

remne, 2024-09-10:
Yes, P1IB only multiply the meter data with the transformer ratio constant, so no precision/resolution should be lost.

Closed 2024-09-09.

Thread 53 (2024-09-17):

Some state values no longer update in MQTT

bjorne, 2024-09-17:
Hi,

I've been running the device for a while and love it. However, I noticed that in Home Assistant the Energy dashboard would just show zero energy usage. After digging around it seems like the active energy import state is not being properly updated in MQTT. It does show a continuously updated value in the P1IB interface, though.

The same goes for a few other fields like the momentary voltage. Other values like the momentary power seem to update just fine.

Here is an example:

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

In Home assistant it looks like this:

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

As you can see, the HA value is ~402 kWh whereas in P1IB it's showing ~1886 kWh, so it's been stuck for a longer time.

The following screenshot from MQTT Explorer shows the values that update continuously highlighted, and most of the ones not highlighted seem stuck:

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

I would like to try to factory reset the device, but let me know if you would like more information to troubleshoot this issue before I do.

remne, 2024-09-17:
Hi,
It looks like you have activated "json state" in your P1IB settings, which probably explains why no messages are sent on the per sensor topics.
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

In your image its not visible, but at least the sensor_state topic is there with the json payload.

Regards,
Andreas

bjorne, 2024-09-17:
Thanks for the suggestion. I should have mentioned I tried to enable this briefly to try and see if there was any difference but the problem seems to exist also in this state, i.e. only some of the properties in the state have a value. The screenshots I shared was from when I had disabled it again (but the topic remains in mqtt, I guess.)

bjorne, 2024-09-17:
Not sure that my point was clear above. When I enable the feature, the JSON state looks like this:

```json{
  "p1ib_hourly_active_import_q1_q4": "",
  "p1ib_hourly_active_export_q2_q3": "",
  "p1ib_hourly_reactive_import_q1_q2": "",
  "p1ib_hourly_reactive_export_q3_q4": "",
  "p1ib_active_power_plus_q1_q4": "",
  "p1ib_active_power_minus_q2_q3": "",
  "p1ib_reactive_power_plus_q1_q2": "",
  "p1ib_reactive_power_minus_q3_q4": "",
  "p1ib_active_power_plus_l1": "",
  "p1ib_active_power_minus_l1": "",
  "p1ib_active_power_plus_l2": "",
  "p1ib_active_power_minus_l2": "",
  "p1ib_active_power_plus_l3": "",
  "p1ib_active_power_minus_l3": "",
  "p1ib_reactive_power_plus_l1": "",
  "p1ib_reactive_power_minus_l1": "",
  "p1ib_reactive_power_plus_l2": "",
  "p1ib_reactive_power_minus_l2": "",
  "p1ib_reactive_power_plus_l3": "",
  "p1ib_reactive_power_minus_l3": "",
  "p1ib_voltage_l1": "",
  "p1ib_voltage_l2": "",
  "p1ib_voltage_l3": "",
  "p1ib_current_l1": "",
  "p1ib_current_l2": "",
  "p1ib_current_l3": "",
  "p1ib_firmware": "f934567",
  "p1ib_update_available": "",
  "p1ib_import_export_l1": 0.042,
  "p1ib_import_export_l2": 0.196,
  "p1ib_import_export_l3": 0.148,
  "p1ib_import_export": 0.386,
  "p1ib_rssi": "-90",
  "p1ib_meter": "KAM5",
  "p1ib_mac": "b0b21ca2350c",
  "p1ib_clock_date": "2024-09-17T11:18:41Z",
  "p1ib_telegrams_crc_ok": 40,
  "p1ib_ip": "192.168.66.37"
}
```

I assume that all the values should be populated?

The diff between two messages looks something like this (with 3-5 updated values)

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

Not sure if this helps narrow it down, but to me it seems to suggest that the reported state is missing some values regardless of whether the JSON state is being used or not?

bjorne, 2024-09-18:
I went ahead and did a factory reset. Reconfigured the same MQTT settings and it is now updating all values as expected. Feel free to close this unless you want to investigate it further.

remne, 2024-09-20:
Its strange indeed. I'm not sure how this error could occur. I've tried to reproduce the problem, but wasn't successful.
Will close the ticket for now, lets see if it pops up again.

Closed 2024-09-20.

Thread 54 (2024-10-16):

MQTT state does not update

MagnusPer, 2024-10-16:
Today I got my new P1IB, great product! My use-case is to get current measurements via MQTT but the states does not updates as shown in local dashboard. Looking in number of messages in MQTT explorer shows no updates!

Firmware version: Build 54aa555

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

MagnusPer, 2024-10-16:
After some reading in closed issues I found this one https://github.com/remne/p1ib/issues/53 which lead me to do a factory reset. Since then it works perfectly

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

remne, 2024-10-17:
Hi,
Thanks for reporting this issue.
I need to dig deeper into this, as you are the second user in a relative short time that have experienced this.

Regards,
Andreas

remne, 2024-11-23:
I think you might have enabled "reduced mode", which in your firmware version sends the clock_date and the calculated power metrics, but not the other ones.

This was the case with the other customer as well.
I will close the ticket, but if you see this issue again in the future, please reopen the issue.

bjorne, 2024-11-24:
I just wanted to clarify that reduced data mode was not the issue in #53 - and doesn't seem to apply here either? It looks to me like we hit the same problem where some state stopped updating without explanation and the only known fix is a factory reset.

remne, 2024-11-24:
It is the reduced mode.
But I still dont know why it was activated (even if the webui didnt show it as enabled or not).

Closed 2024-11-23.

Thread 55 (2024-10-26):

Entites (solar) in Home Assistant.

Newman820, 2024-10-26:
Entites present as "P1IB Active power L1 (solar)", "P1IB Active power L2 (solar)" and "P1IB Active power L3 (solar)" in Home Assistant represents import from grid and should not have "(solar)" in its name.

If "solar" should be preset it should be on "P1IB Active power minus L1", "P1IB Active power minus L2" and "P1IB Active power minus L1" which represent export to grid.

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

remne, 2024-10-26:
The 'solar' part of the name is already removed in latest dev firmware that will be pushed in the coming days.

But it will not be added to the power minus sensors.

Closed 2024-10-26.

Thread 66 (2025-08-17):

Feature request: power tariff helper

janakelarsson, 2025-08-17:
My provider charges a power tariff: I pay a fee proportional to the average of the five highest power-consuming hours in the month. The provider tells me the meter calculates the power consumption per hour and selects the five highest. Aidon 6534.

I will likely write my own helpers within HA to keep track of this but it would help to have the actual numbers used by the provider.

janakelarsson, 2025-09-05:
If the data is not available in the meter it is better to do it in HA. I was going to close the issue but perhaps you could make use of the diagram helpers I have made in HA so far, will post those here when I have time.

remne, 2025-09-05:
OK, so just for the sake of it, another issue reported ( https://github.com/remne/p1ib/issues/67 ) it seems that power meters in sweden is starting to output more data than is specified by the "p1 standard" in sweden.

I haven't come across any meter that actually add data for it in sweden - until today.

So to be sure, if you're willing, lets check what your meter outputs.

Can you try to get some debug logs from your P1IB? By following this guide, https://remne.tech/p1ib-guide/ in the chapter about debug logs.

Regards,
Andreas

janakelarsson, 2025-09-06:
Site seems to be down

janakelarsson, 2025-09-06:
Second cards, shows hourly consumption for 31 preceding days. The selection tools in the UI allows you to select one or more to show. Code is long, I couldn't find a simple way to shorten the series entity list.

```
type: custom:config-template-card
entities: sensor.p1ib_active_energy_import_q1_q4
grid_options:
  columns: full
variables:
  date: new Date();
  month:
    - " Jan"
    - " Feb"
    - " Mar"
    - " Apr"
    - " Jun"
    - " Jul"
    - " Aug"
    - " Sep"
    - " Oct"
    - " Nov"
    - " Dec"
card:
  type: custom:apexcharts-card
  experimental:
    disable_config_validation: true
  header:
    show: true
    title: Förbrukning per timme
  graph_span: 24h
  span:
    start: day
  now:
    show: true
  all_series_config:
    entity: sensor.p1ib_active_energy_import_q1_q4
    extend_to: now
    show:
      legend_value: false
      offset_in_name: false
      extremas: max
    statistics:
      type: change
      period: hour
  yaxis:
    - min: 0
  series:
    - offset: "-0d"
      name: >-
        ${ date.setDate(date.getDate()-0);
        date.getDate()+month[date.getMonth()-1] }
    - offset: "-1d"
      name: >-
        ${ date.setDate(date.getDate()-1);
        date.getDate()+month[date.getMonth()-1] }
    - offset: "-2d"
      name: >-
        ${ date.setDate(date.getDate()-2);
        date.getDate()+month[date.getMonth()-1] }
    - offset: "-3d"
      name: >-
        ${ date.setDate(date.getDate()-3);
        date.getDate()+month[date.getMonth()-1] }
    - offset: "-4d"
      name: >-
        ${ date.setDate(date.getDate()-4);
        date.getDate()+month[date.getMonth()-1] }
    - offset: "-5d"
      name: >-
        ${ date.setDate(date.getDate()-5);
        date.getDate()+month[date.getMonth()-1] }
    - offset: "-6d"
      name: >-
        ${ date.setDate(date.getDate()-6);
        date.getDate()+month[date.getMonth()-1] }
    - offset: "-7d"
      name: >-
        ${ date.setDate(date.getDate()-7);
        date.getDate()+month[date.getMonth()-1] }
    - offset: "-8d"
      name: >-
        ${ date.setDate(date.getDate()-8);
        date.getDate()+month[date.getMonth()-1] }
    - offset: "-9d"
      name: >-
        ${ date.setDate(date.getDate()-9);
        date.getDate()+month[date.getMonth()-1] }
    - offset: "-10d"
      name: >-
        ${ date.setDate(date.getDate()-10);
        date.getDate()+month[date.getMonth()-1] }
    - offset: "-11d"
      name: >-
        ${ date.setDate(date.getDate()-11);
        date.getDate()+month[date.getMonth()-1] }
    - offset: "-12d"
      name: >-
        ${ date.setDate(date.getDate()-12);
        date.getDate()+month[date.getMonth()-1] }
    - offset: "-13d"
      name: >-
        ${ date.setDate(date.getDate()-13);
        date.getDate()+month[date.getMonth()-1] }
    - offset: "-14d"
      name: >-
        ${ date.setDate(date.getDate()-14);
        date.getDate()+month[date.getMonth()-1] }
    - offset: "-15d"
      name: >-
        ${ date.setDate(date.getDate()-15);
        date.getDate()+month[date.getMonth()-1] }
    - offset: "-16d"
      name: >-
        ${ date.setDate(date.getDate()-16);
        date.getDate()+month[date.getMonth()-1] }
    - offset: "-17d"
      name: >-
        ${ date.setDate(date.getDate()-17);
        date.getDate()+month[date.getMonth()-1] }
    - offset: "-18d"
      name: >-
        ${ date.setDate(date.getDate()-18);
        date.getDate()+month[date.getMonth()-1] }
    - offset: "-19d"
      name: >-
        ${ date.setDate(date.getDate()-19);
        date.getDate()+month[date.getMonth()-1] }
    - offset: "-20d"
      name: >-
        ${ date.setDate(date.getDate()-20);
        date.getDate()+month[date.getMonth()-1] }
    - offset: "-21d"
      name: >-
        ${ date.setDate(date.getDate()-21);
        date.getDate()+month[date.getMonth()-1] }
    - offset: "-22d"
      name: >-
        ${ date.setDate(date.getDate()-22);
        date.getDate()+month[date.getMonth()-1] }
    - offset: "-23d"
      name: >-
        ${ date.setDate(date.getDate()-23);
        date.getDate()+month[date.getMonth()-1] }
    - offset: "-24d"
      name: >-
        ${ date.setDate(date.getDate()-24);
        date.getDate()+month[date.getMonth()-1] }
    - offset: "-25d"
      name: >-
        ${ date.setDate(date.getDate()-25);
        date.getDate()+month[date.getMonth()-1] }
    - offset: "-26d"
      name: >-
        ${ date.setDate(date.getDate()-26);
        date.getDate()+month[date.getMonth()-1] }
    - offset: "-27d"
      name: >-
        ${ date.setDate(date.getDate()-27);
        date.getDate()+month[date.getMonth()-1] }
    - offset: "-28d"
      name: >-
        ${ date.setDate(date.getDate()-28);
        date.getDate()+month[date.getMonth()-1] }
    - offset: "-29d"
      name: >-
        ${ date.setDate(date.getDate()-29);
        date.getDate()+month[date.getMonth()-1] }
    - offset: "-30d"
      name: >-
        ${ date.setDate(date.getDate()-30);
        date.getDate()+month[date.getMonth()-1] }

```

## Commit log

2021-07-01 Stable version.
    [ledthingy.dxf, p1ib_bottom.stl, p1ib_top.stl]
2021-07-26 torstein 3, l3 voltage obis typo and disable fw update logging
2021-08-05 Add firwmare 0a2e32f with power consumption modifications in AP mode
2021-08-06 Add firmware 743beb1 with wifi tx power changes in ap mode and upramping in normal mode
2021-10-30 add ha energy image and updated stls for plastic case
    [p1ib_bottom.stl, p1ib_top.stl]
2021-11-08 add firmware 4077b50 device configuration_url and connections mac
2022-02-05 added a couple of missed changes in the changelog for latest dev firmware
2023-04-27 add power meter modes image
2023-08-21 add dev fw ca6d4a7 p1ib-ext fuse support
2023-10-11 add dev fw 4afb28e - improve json payload and HA mqtt discovery ui switch
2023-10-17 add dev fw 376ff2 fix clock date sensor in json payload
2024-02-12 add dev fw 6a543ea additional main fuse values
2025-07-22 add dev fw 0d46bd6, HA device class for reactive power and energy
2025-09-13 add dev fw 757b45d, HA reactive sensors update + mTLS userpass
